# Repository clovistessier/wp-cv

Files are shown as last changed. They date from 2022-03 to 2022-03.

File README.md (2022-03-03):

# Waaave_Pool Eurorack CV Interface Module
The Waaave_Pool Eurorack CV Interface Module is a Eurorack module that allows you to use control voltage from a Eurorack modular synthesizer to modulate any of the 16 continuous parameters of the Waaave_Pool video synthesis system. Use CV from LFOs, sequencers, envelopes, S+H, and more to animate your video feedback. Used in conjuction with a conventional Eurorack synth patch, you can achieve nuanced syncing between your audio and video for a cohesive audiovisual performance. Due to the framebuffer based implementation of Waaave_Pool, the best visual results are using CV that changes at a speed lower than the framerate of the system.

## Revision B.
This version of the module connects directly to the GPIO pins of the Raspberry Pi 3B+ running Waaave_Pool. A limited run of these modules was produced and sold in August 2020. This version is intended to be used with LZX compatible eurorack modules and complies with the [LZX Patchable Video Standard](https://community.lzxindustries.net/t/the-lzx-patchable-video-standard/842) for "Animation Speed" CV (<30Hz), whereas +/-1V corresponds to +/-100% of the parameters range.
### Features
- 16 CV inputs expecting +/-1V (+/-12V tolerant)
- Bipolar attenuator aka attenuverter (-n to n) on each input
- Positive and Negative clipping for voltages outside the expected range
### Usage
All of the files required to build your own are included. You can upload the zipped gerber files to your PCB manufacturer of choice (JLCPCB has been used successfully in the past). Ordering an SMT stencil with the board is highly recommended due to the large quantity of SMD components. 

The KiCAD project files are also included, open the .pro file with KiCAD to view the project.

[Mouser Project Link](https://www.mouser.com/ProjectManager/ProjectDetail.aspx?AccessID=e002599eb7) for easy parts ordering. Don't forget the knobs and jacks from [Thonk](thonk.co.uk)!

The included front panel gerber files can be used to order an FR-4 front panel at the same time as the PCBs. You may get a follow up email from the PCB manufacturer since they assume that a PCB with no copper traces is probably unintentional.

To use the module with Waaave_Pool, you will need a 40-Pin IDC ribbon cable to connect betweent the header at the bottom of the module and the GPIO header of the Raspberry Pi. You will also need to be running a CV-compatible firmware version, which can be found all the way at the bottom of the [VSERPI Hardware and Images page](https://andreijaycreativecoding.com/VSERPI-hardware-and-images).

## Revision C. (WIP)
This version of the module incorporates an ESP32 microcontroller to handle the analog to digital conversion, and trasmits the information using [OSC](https://ccrma.stanford.edu/groups/osc/index.html) to Waaave_Pool over Ethernet and/or Wi-Fi. This version is intended to work with +/-5V control voltage, allowing for a much wider range of compatible CV sources from the Eurorack world, beyond just LZX. Due to the inherent flexibility of OSC, this module could also be used to send CV information to something other than Waaave_Pool, such as an application running on your computer. Development is still ongoing.

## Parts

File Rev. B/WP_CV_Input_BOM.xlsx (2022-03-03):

Reference | Quantity | Value | Footprint | Vendor | Mouser P/N | Price | Ext. Price | Website | Description
C1 C2 | 2 | 10u 25V | Capacitor_THT:CP_Radial_D5.0mm_P2.00mm | Mouser | 667-ECE-A1VKS100 | $0.28 | $0.56 | https://www.mouser.com/ProductDetail/667-ECE-A1VKS100 | Aluminum Electrolytic Capacitors - Radial Leaded 10UF 35V KS RADIAL
C11 C12 | 2 | 10u | Capacitor_Tantalum_SMD:CP_EIA-2012-15_AVX-P | Mouser | 74-TMCP0J106MTRF | $0.36 | $0.72 | https://www.mouser.com/ProductDetail/74-TMCP0J106MTRF | Tantalum Capacitors - Solid SMD 7volts 10uF 20% Molded Case, 0805
C13 C14 C15 C16 C17 C18 C19 C20 C21 C22 C23 C24 C25 C26 C27 C28 C29 C3 C30 C31 C32 C33 C34 C35 C36 C37 C38 C39 C4 C40 C41 C42 C43 C44 C5 C6 C8 C9 | 38 | 100n | Capacitor_SMD:C_0603_1608Metric | Mouser | 80-C0603C104Z3V | $0.03 | $1.22 | https://www.mouser.com/ProductDetail/80-C0603C104Z3V | Multilayer Ceramic Capacitors MLCC - SMD/SMT 25V 0.1uF 0603 Y5V -20/+80%
C10 C7 | 2 | 1u | Capacitor_SMD:C_0603_1608Metric | Mouser | 80-C0603C105K9P | $0.10 | $0.20 | https://www.mouser.com/ProductDetail/80-C0603C105K9P | Multilayer Ceramic Capacitors MLCC - SMD/SMT 1uF 16.0V
D1 D2 | 2 | SM4001 | Diode_SMD:D_SOD-123 | Mouser | 833-SM4001PL-TP | $0.20 | $0.40 | https://www.mouser.com/ProductDetail/833-SM4001PL-TP | Rectifiers Standard 50V 1A
D3 | 1 | LM4040DBZ-2.0 | Package_TO_SOT_SMD:SOT-23 | Mouser | 700-LM4040AEM3-2.1T | $2.36 | $2.36 | https://www.mouser.com/ProductDetail/700-LM4040AEM3-2.1T | Voltage References Improved Precision Micropower Shunt Voltage Reference with Multiple Reverse Breakdown Voltages
D10 D11 D12 D13 D14 D15 D16 D17 D18 D19 D20 D21 D22 D23 D24 D25 D26 D27 D28 D29 D30 D31 D32 D33 D34 D35 D4 D5 D6 D7 D8 D9 | 32 | 1N4148W | Diode_SMD:D_SOD-123 | Mouser | 621-1N4148W-F | $0.16 | $5.12 | https://www.mouser.com/ProductDetail/621-1N4148W-F | Diodes - General Purpose, Power, Switching SURFACE MOUNT FAST SWITCHING DIODE
FB1 FB2 | 2 | Ferrite_Bead | Inductor_SMD:L_0603_1608Metric | Mouser | 875-MI0603J680R-10 | $0.10 | $0.20 | https://www.mouser.com/ProductDetail/875-MI0603J680R-10 | Ferrite Beads 68ohms 100MHz 1A Monolithic 0603 SMD
J1 | 1 | Eurorack_Power_Header_02x08 | Connector_PinHeader_2.54mm:PinHeader_2x08_P2.54mm_Vertical | Mouser | 649-1012938191601BLF | $0.48 | $0.48 | https://www.mouser.com/ProductDetail/649-1012938191601BLF | Headers & Wire Housings ECONOSTIK HEADER DR VT TH 2X8
J2 | 1 | Raspberry_Pi_2_3_GPIO_Header | Connector_PinHeader_2.54mm:PinHeader_2x20_P2.54mm_Vertical | Mouser | 649-1012938194002BLF | $1.11 | $1.11 | https://www.mouser.com/ProductDetail/649-1012938194002BLF | Headers & Wire Housings ECONOSTIK HEADER DR VT TH 2X20
R1 R109 R110 R112 R113 R115 R116 R118 R119 R120 R121 R122 R123 R13 R14 R16 R17 R19 R2 R20 R22 R23 R24 R25 R26 R27 R45 R46 R48 R49 R51 R52 R54 R55 R56 R57 R58 R59 R77 R78 R80 R81 R83 R84 R86 R87 R88 R89 R90 R91 | 50 | 10K | Resistor_SMD:R_0603_1608Metric | Mouser | 667-ERJ-3EKF1002V | $0.05 | $2.50 | https://www.mouser.com/ProductDetail/667-ERJ-3EKF1002V | Thick Film Resistors - SMD 0603 10Kohms 1% AEC-Q200
R124 R125 R126 R127 R128 R129 R130 R131 R28 R29 R30 R31 R32 R33 R34 R35 R60 R61 R62 R63 R64 R65 R66 R67 R92 R93 R94 R95 R96 R97 R98 R99 | 32 | 1K | Resistor_SMD:R_0603_1608Metric | Mouser | 667-ERJ-PA3F1001V | $0.06 | $1.92 | https://www.mouser.com/ProductDetail/667-ERJ-PA3F1001V | Thick Film Resistors - SMD 0603 1Kohm 1% Anti-Surge AEC-Q200
R108 R111 R114 R117 R12 R15 R18 R21 R3 R44 R47 R50 R53 R76 R79 R82 R85 | 17 | 4.99K | Resistor_SMD:R_0603_1608Metric | Mouser | 603-RC0603FR-104K99L | $0.02 | $0.34 | https://www.mouser.com/ProductDetail/603-RC0603FR-104K99L | Thick Film Resistors - SMD 4.99K ohm 1% 75V General Purpose
R100 R101 R102 R103 R36 R37 R38 R39 R4 R5 R6 R68 R69 R7 R70 R71 | 16 | 100K | Resistor_SMD:R_0603_1608Metric | Mouser | 603-RC0603FR-07100KL | $0.02 | $0.32 | https://www.mouser.com/ProductDetail/603-RC0603FR-07100KL | Thick Film Resistors - SMD 100K OHM 1%
R10 R104 R105 R106 R107 R11 R40 R41 R42 R43 R72 R73 R74 R75 R8 R9 | 16 | 499R | Resistor_SMD:R_0603_1608Metric | Mouser | 71-CRCW0603-499-E3 | $0.03 | $0.48 | https://www.mouser.com/ProductDetail/71-CRCW0603-499-E3 | Thick Film Resistors - SMD 1/10watt 499ohms 1%
U1 U2 | 2 | MCP3008 | Package_SO:SOIC-16_3.9x9.9mm_P1.27mm | Mouser | 579-MCP3008T-I/SL | $2.19 | $4.38 | https://www.mouser.com/ProductDetail/579-MCP3008T-I-SL | Analog to Digital Converters - ADC 10-bit SPI 8 Chl IND TEMP, SOIC16
U3 | 1 | TL072 | Package_SO:SOIC-8_3.9x4.9mm_P1.27mm | Mouser | 595-TL072CDR | $0.41 | $0.41 | https://www.mouser.com/ProductDetail/595-TL072CDR | Operational Amplifiers - Op Amps Dual JFET Op Amp
U10 U11 U12 U13 U14 U15 U16 U17 U18 U19 U4 U5 U6 U7 U8 U9 | 16 | TL074 | Package_SO:SOIC-14_3.9x8.7mm_P1.27mm | Mouser | 511-TL074IDT | $0.48 | $7.68 | https://www.mouser.com/ProductDetail/511-TL074IDT | Operational Amplifiers - Op Amps Quad Low Noise JFET
J10 J11 J12 J13 J14 J15 J16 J17 J18 J3 J4 J5 J6 J7 J8 J9 | 16 | Thonkiconn_Mono | Connector_Audio_Extra:Jack_3.5mm_QingPu_WQP-PJ398SM_Vertical_CircularHoles_Numbered_Pads | Thonk |  | $0.43 | $6.88 | https://www.thonk.co.uk/shop/thonkiconn/ | Thonkiconn Mono 3.5mm Audio Jack
RV1 RV10 RV11 RV12 RV13 RV14 RV15 RV16 RV2 RV3 RV4 RV5 RV6 RV7 RV8 RV9 | 16 | B10K Center Detent | Potentiometer_THT_Extra:Potentiometer_Alpha_RD901F-40-00D_Single_Vertical_CircularHoles | Thonk |  | $1.04 | $16.64 | https://www.thonk.co.uk/shop/ttpots/ | Song Huei 9mm Tall Trimmer Potentiometer
 |  |  |  |  |  | Total Price: | $53.92
 |  |  |  |  |  |  |  | Mouser Project Page:
 |  |  |  |  |  |  |  | https://www.mouser.com/ProjectManager/ProjectDetail.aspx?AccessID=e002599eb7

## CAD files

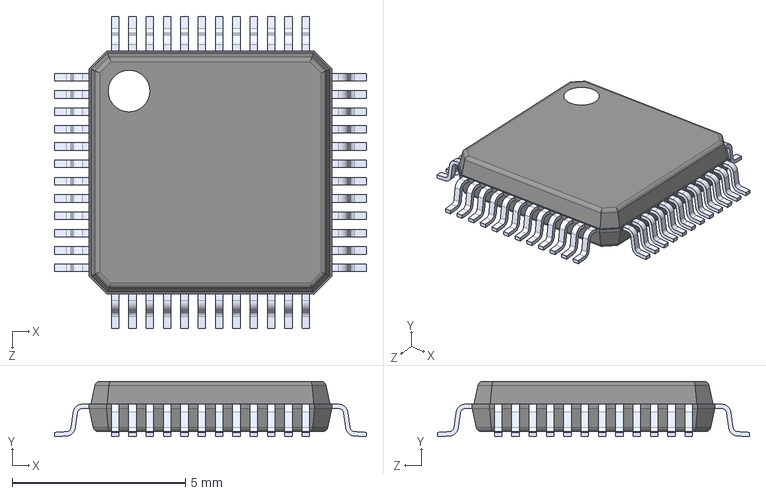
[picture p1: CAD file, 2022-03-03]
Rev. C/Hardware Design Files/KiCAD Project Files/PROJECT_SYMBOLS/W5500/W5500.step
9.00 x 1.60 x 9.00 mm

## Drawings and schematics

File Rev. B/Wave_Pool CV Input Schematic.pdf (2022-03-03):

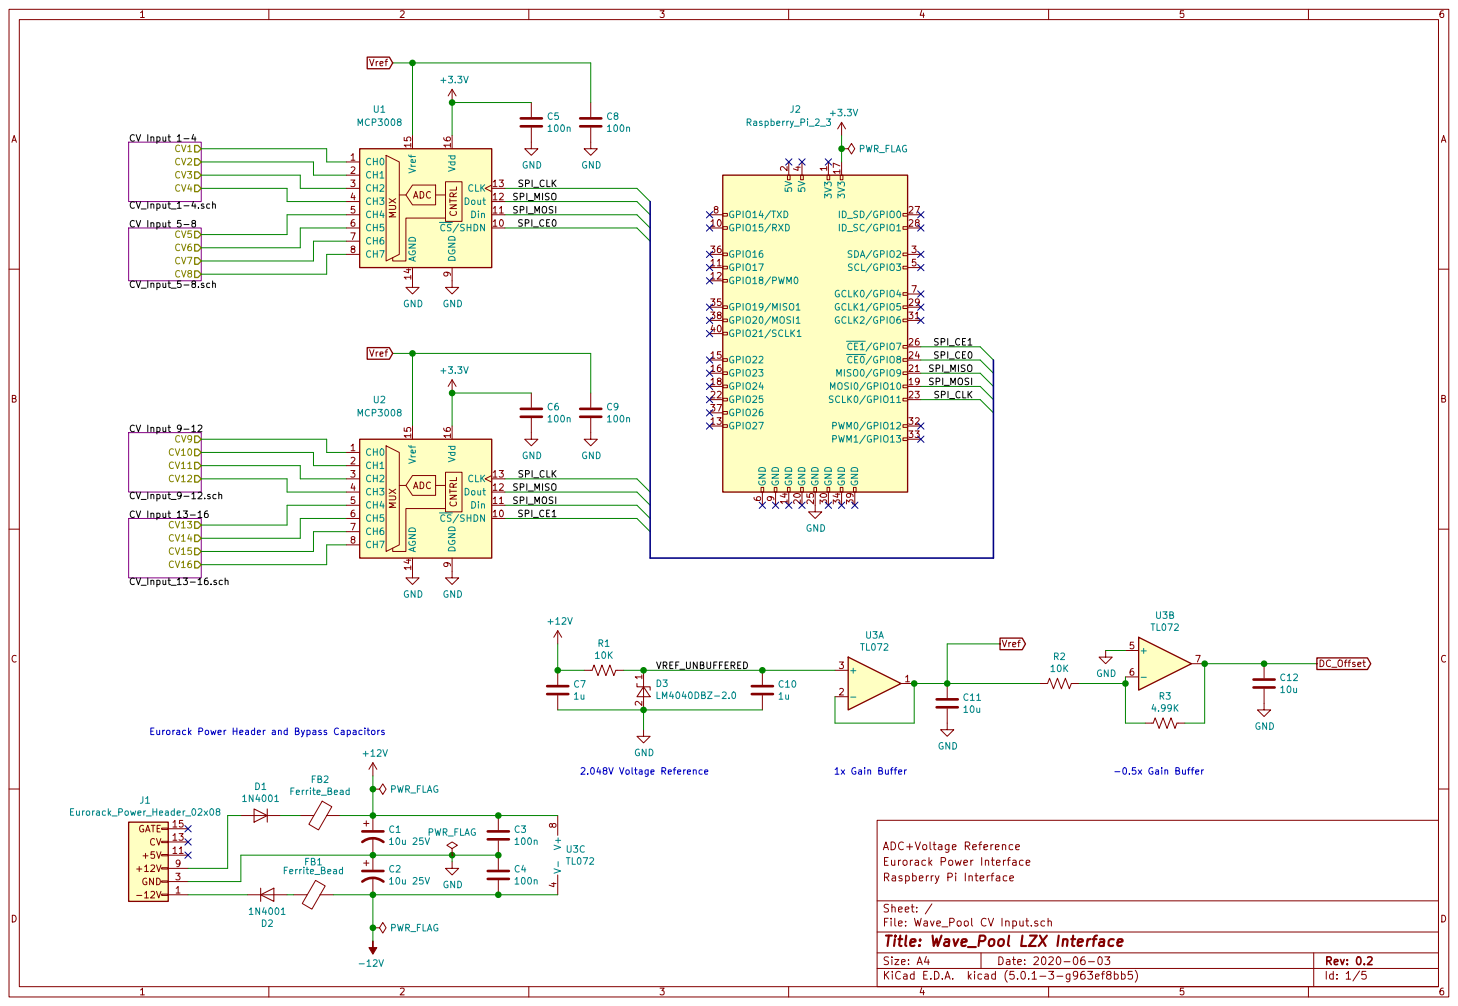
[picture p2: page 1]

9 U1 MCP3008 ADC MUX CNTRL CH0 1 CS/SHDN 10 Din 11 Dout 12 CLK 13 AGND 14 Vref 15 Vdd 16 CH1 2 CH2 3 CH3 4 CH4 5 CH5 6 CH6 7 CH7 8 DGND

File: Wave_Pool CV Input.sch Sheet: / Raspberry Pi Interface Eurorack Power Interface ADC+Voltage Reference

Id: 1/5 Title: Wave_Pool LZX Interface

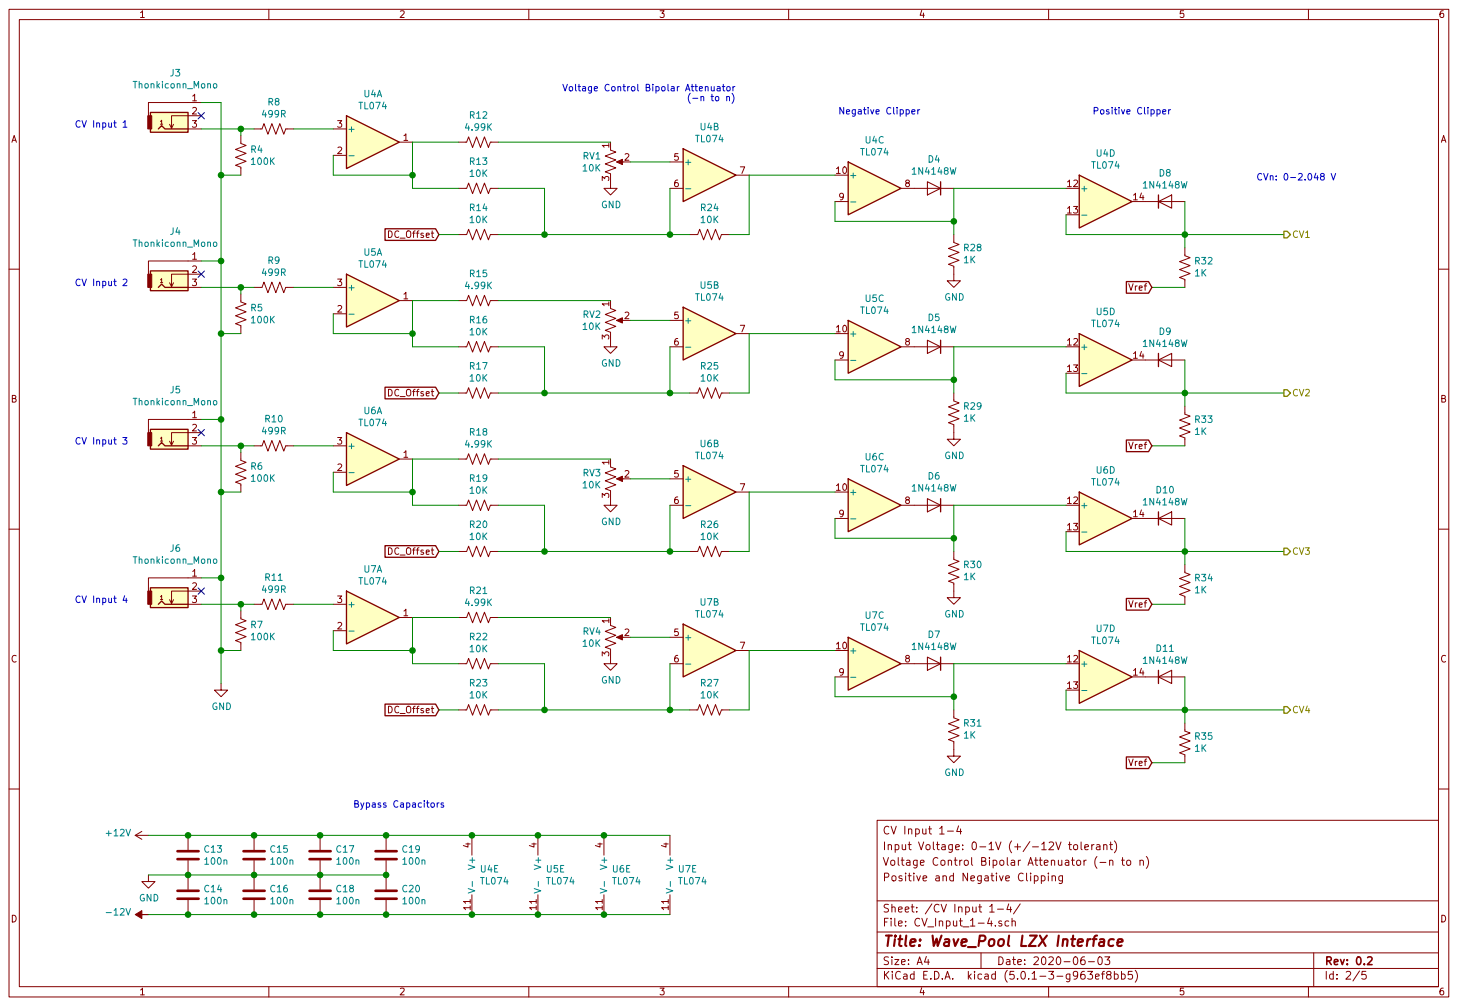
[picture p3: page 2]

Voltage Control Bipolar Attenuator

Input Voltage: 0-1V (+/-12V tolerant)
Voltage Control Bipolar Attenuator (-n to n)
Positive and Negative Clipping

Sheet: /CV Input 1-4/
File: CV_Input_1-4.sch
Id: 2/5 Title: Wave_Pool LZX Interface

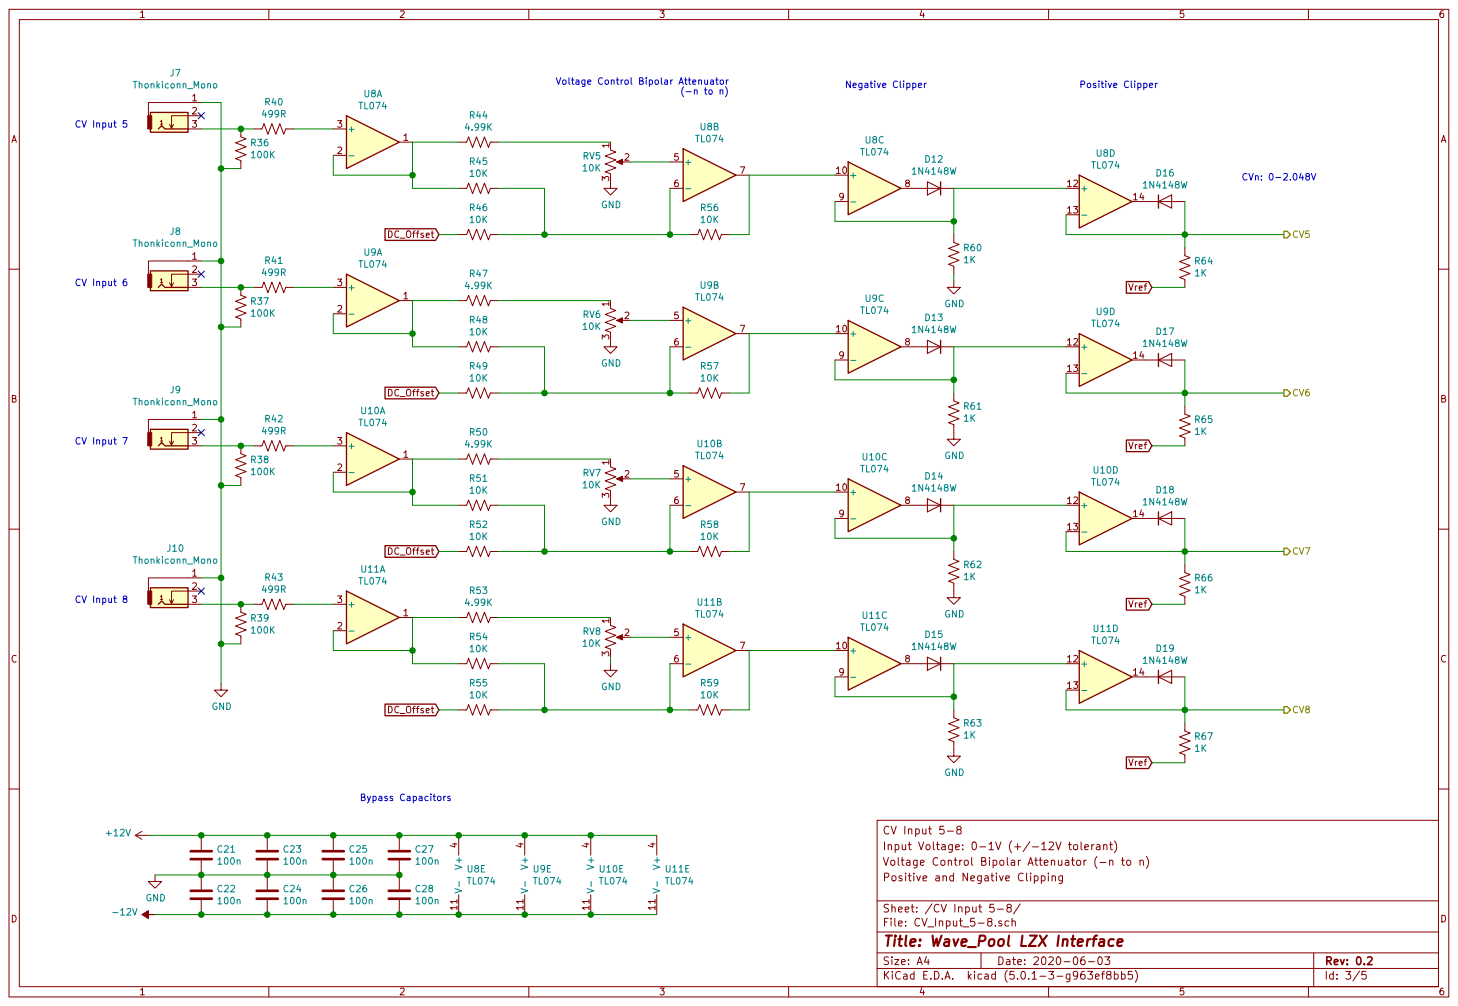
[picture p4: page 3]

Voltage Control Bipolar Attenuator

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

Sheet: /CV Input 5-8/
File: CV_Input_5-8.sch
Id: 3/5 Title: Wave_Pool LZX Interface

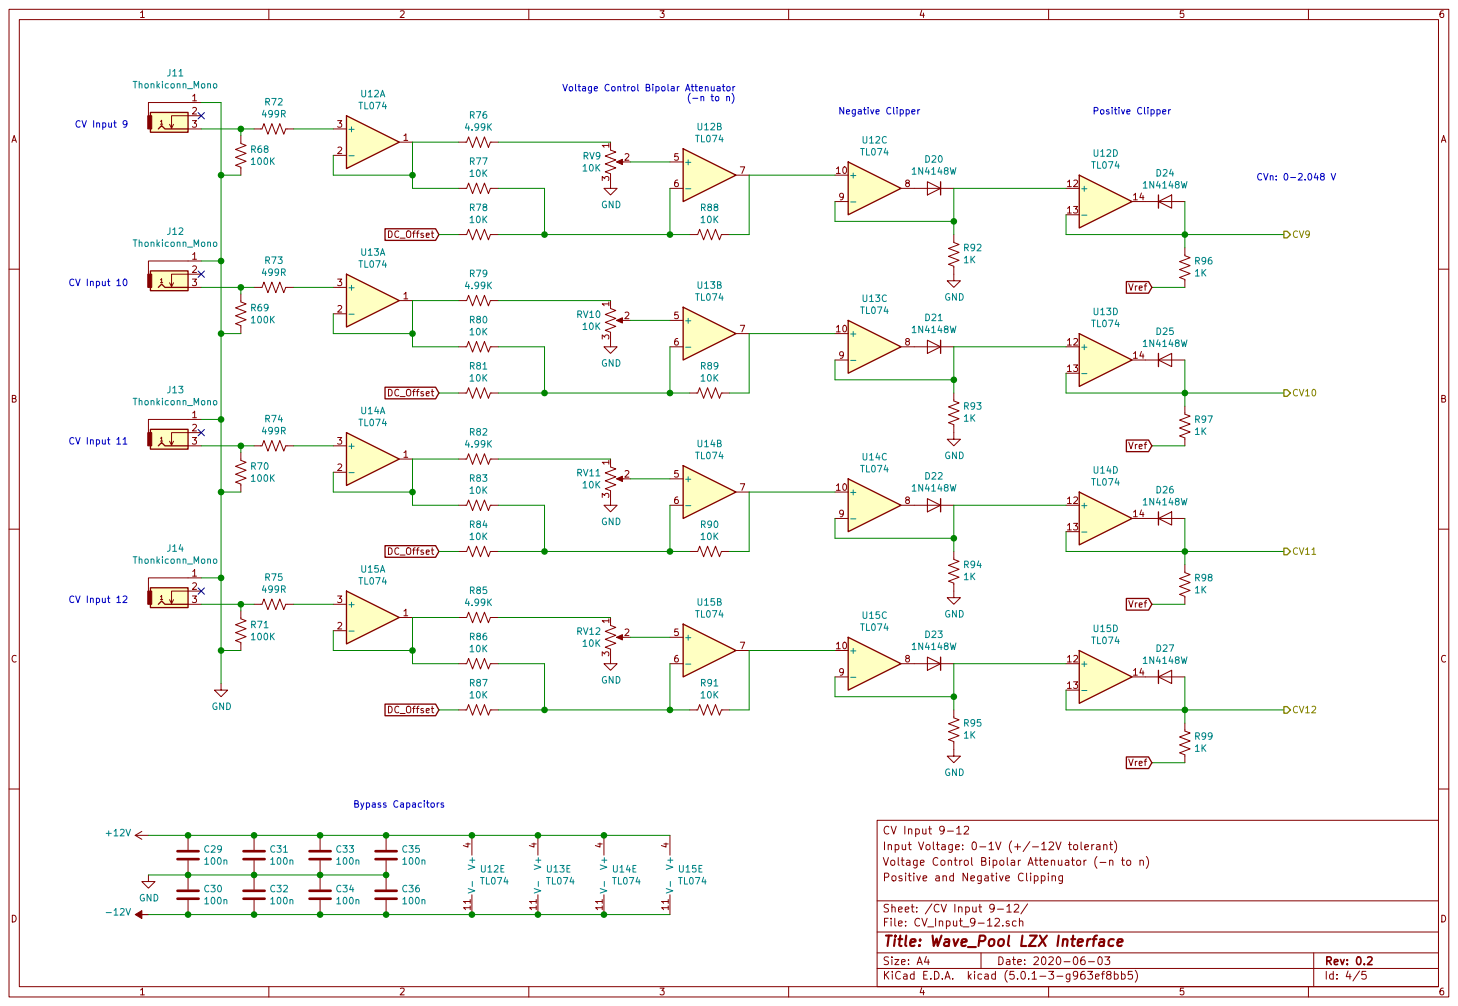
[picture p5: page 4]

Voltage Control Bipolar Attenuator

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

Sheet: /CV Input 9-12/
File: CV_Input_9-12.sch
Id: 4/5 Title: Wave_Pool LZX Interface

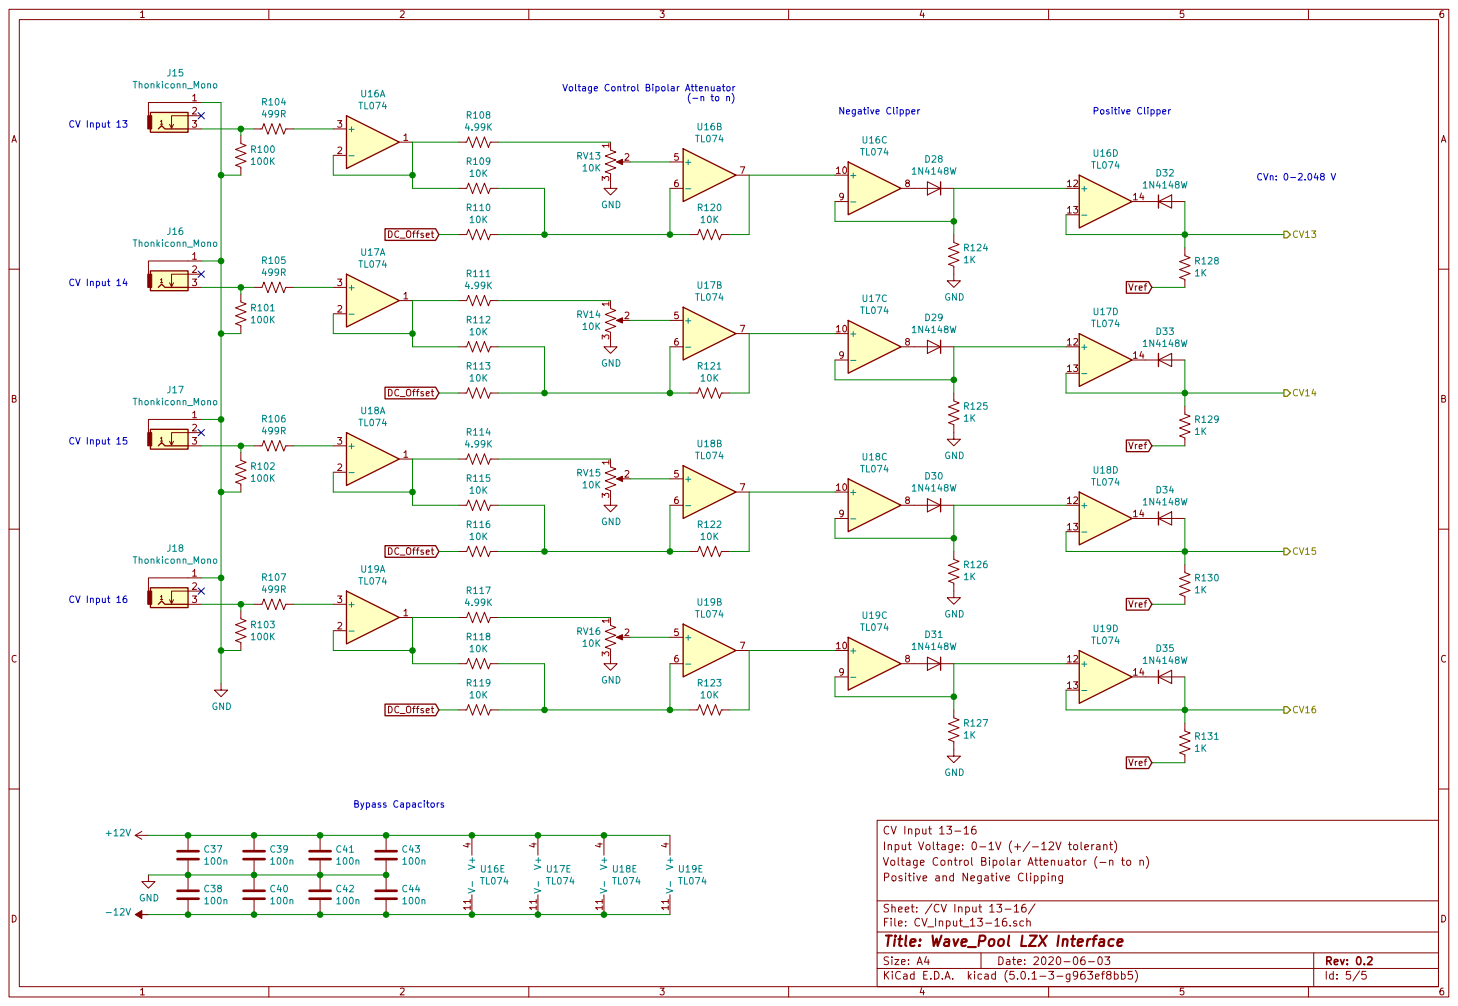
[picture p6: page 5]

Voltage Control Bipolar Attenuator

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

Sheet: /CV Input 13-16/
File: CV_Input_13-16.sch
Id: 5/5 Title: Wave_Pool LZX Interface

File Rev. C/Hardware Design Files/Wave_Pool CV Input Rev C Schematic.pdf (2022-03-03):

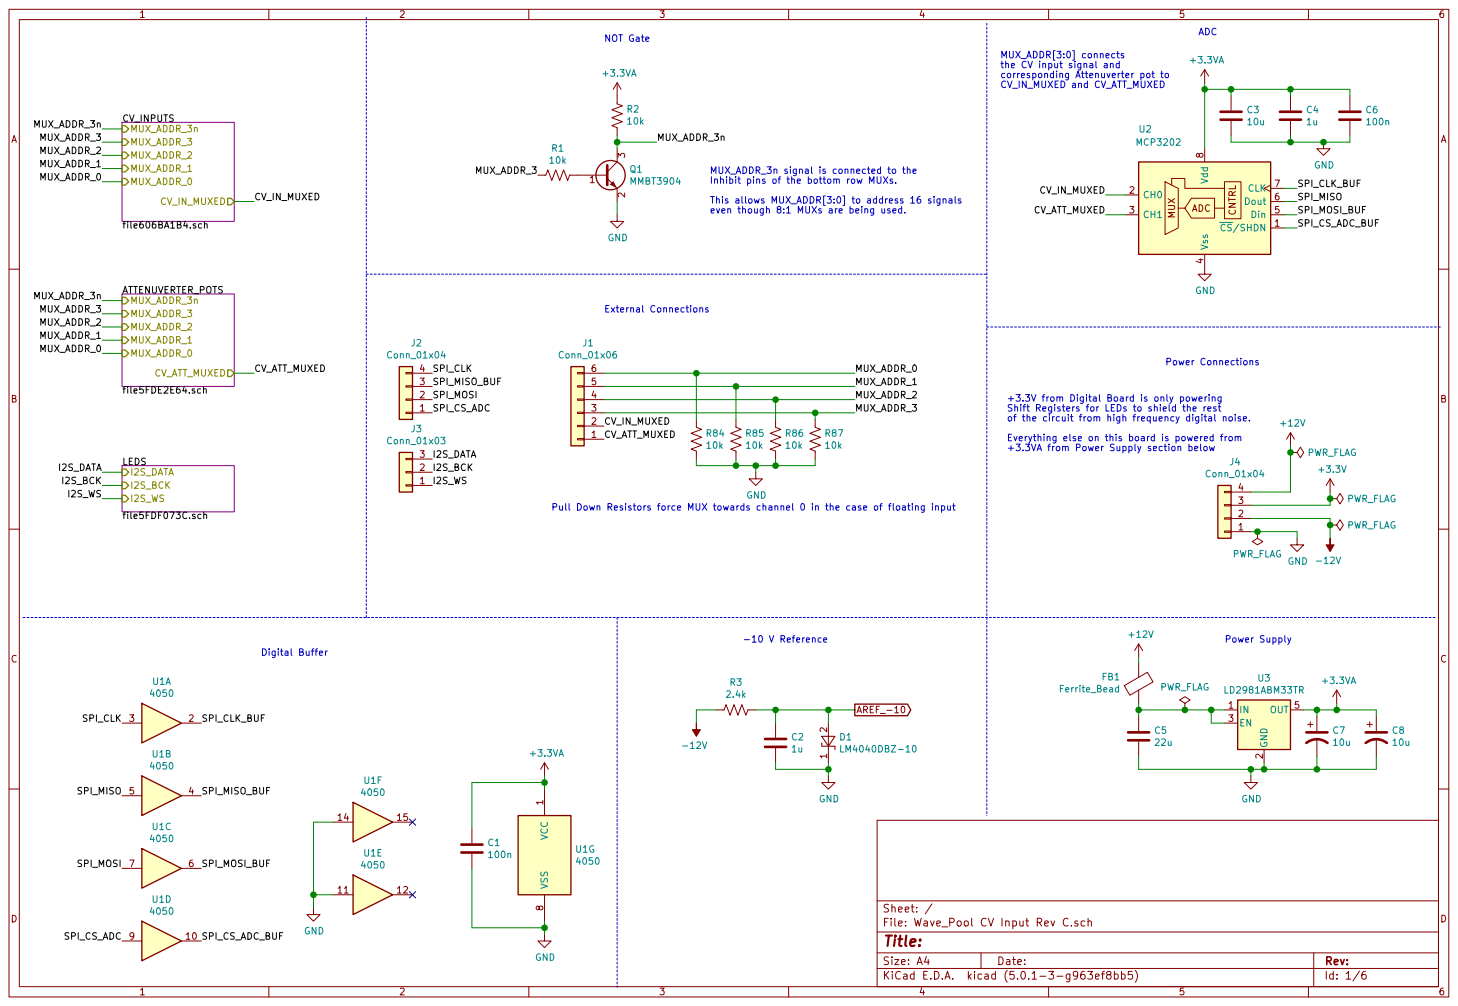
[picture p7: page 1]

MUX_ADDR[3:0] connects
the CV input signal and
corresponding Attenuverter pot to CV_IN_MUXED and CV_ATT_MUXED

MUX_ADDR_3n signal is connected to the
Inhibit pins of the bottom row MUXs.
This allows MUX_ADDR[3:0] to address 16 signals
even though 8:1 MUXs are being used.

+3.3V from Digital Board is only powering
Shift Registers for LEDs to shield the rest
of the circuit from high frequency digital noise.
Everything else on this board is powered from
+3.3VA from Power Supply section below

Pull Down Resistors force MUX towards channel 0 in the case of floating input

File: Wave_Pool CV Input Rev C.sch Sheet: /
Id: 1/6 Title:

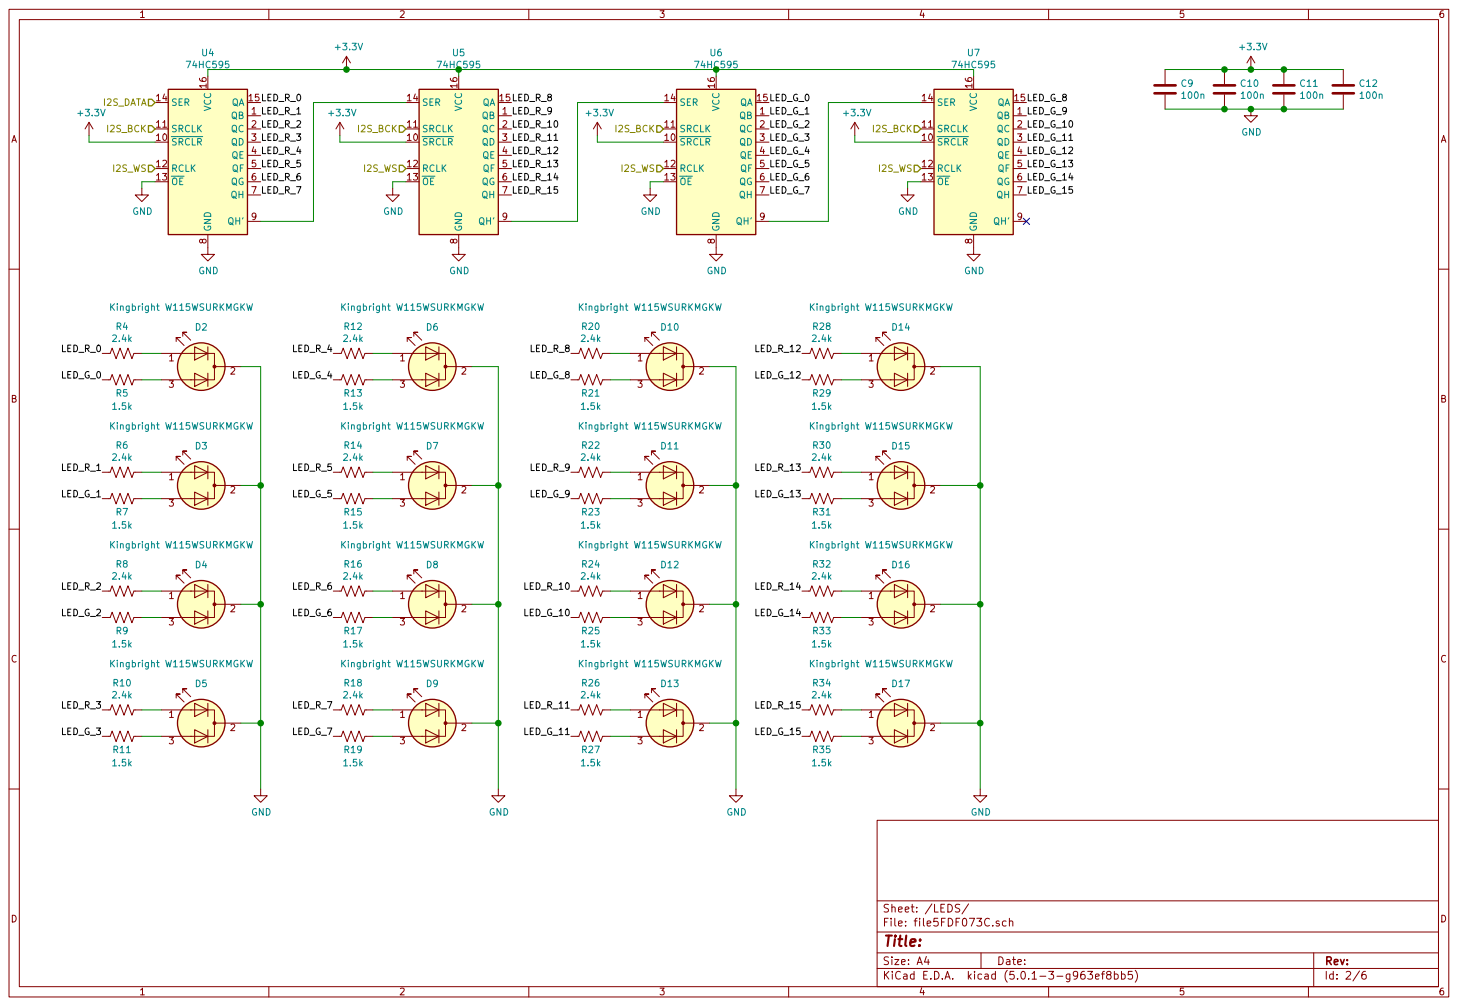
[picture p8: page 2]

Id: 2/6 Title: File: file5FDF073C.sch Sheet: /LEDS/

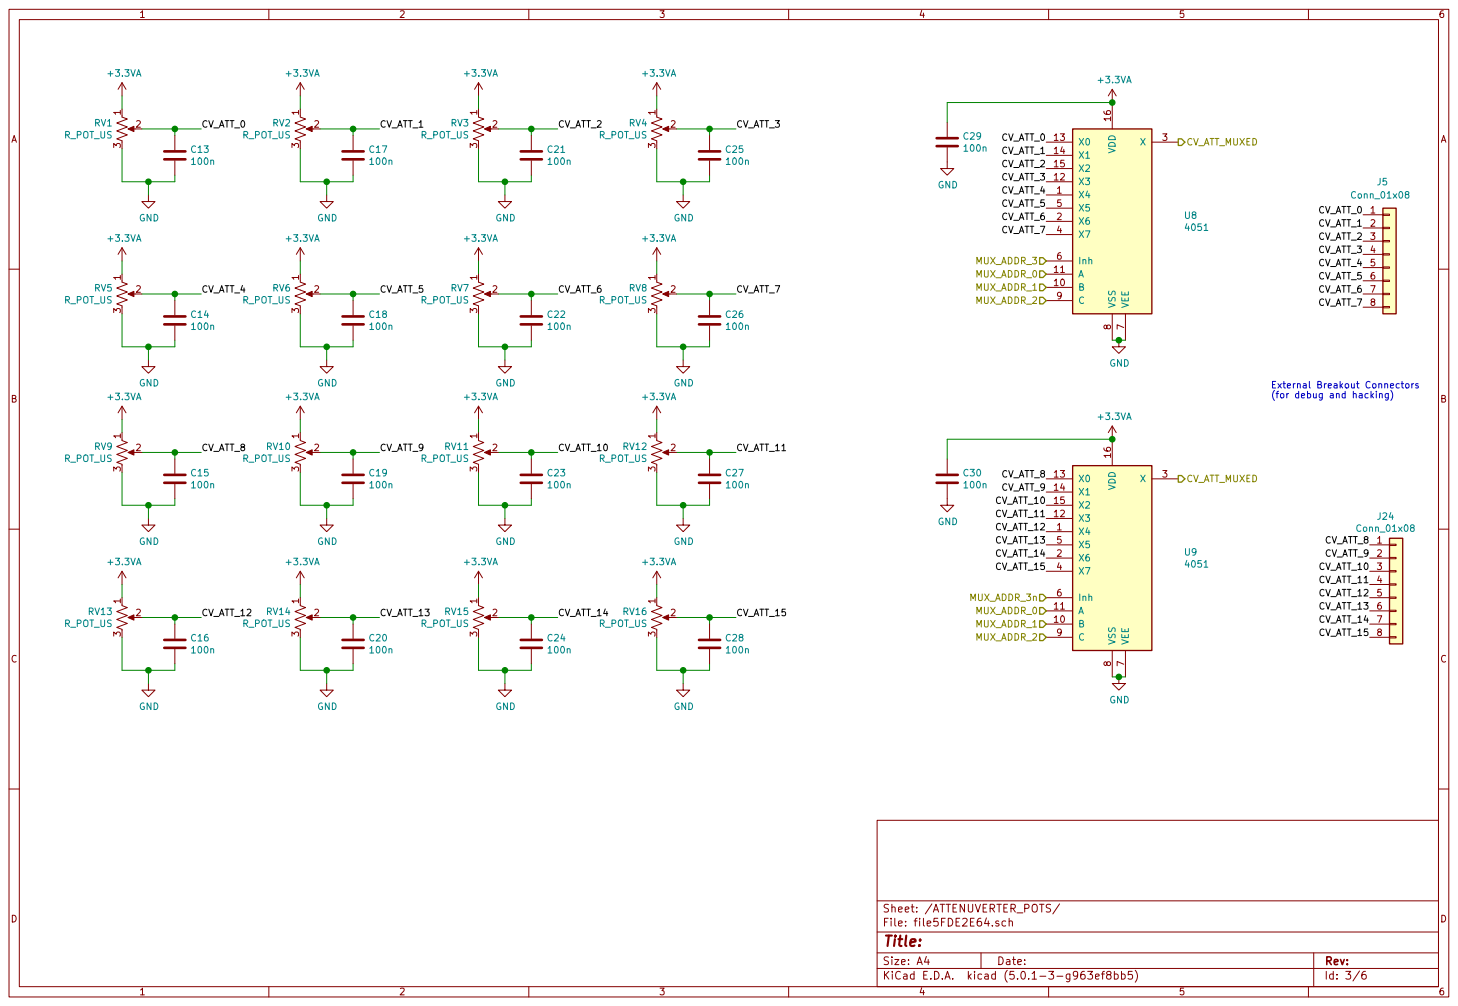
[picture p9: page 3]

J24 Conn_01x08 External Breakout Connectors
(for debug and hacking)

Id: 3/6 Title: File: file5FDE2E64.sch Sheet: /ATTENUVERTER_POTS/

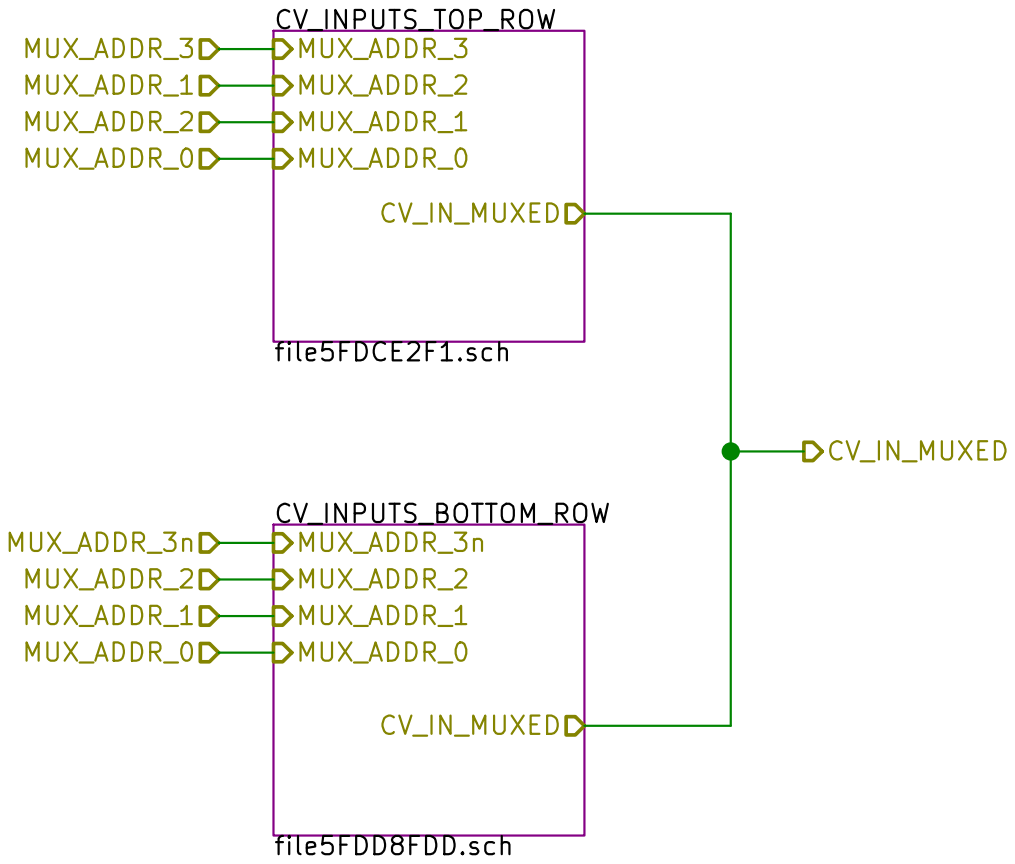
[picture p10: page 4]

Id: 4/6 Title: File: file606BA1B4.sch Sheet: /CV_INPUTS/

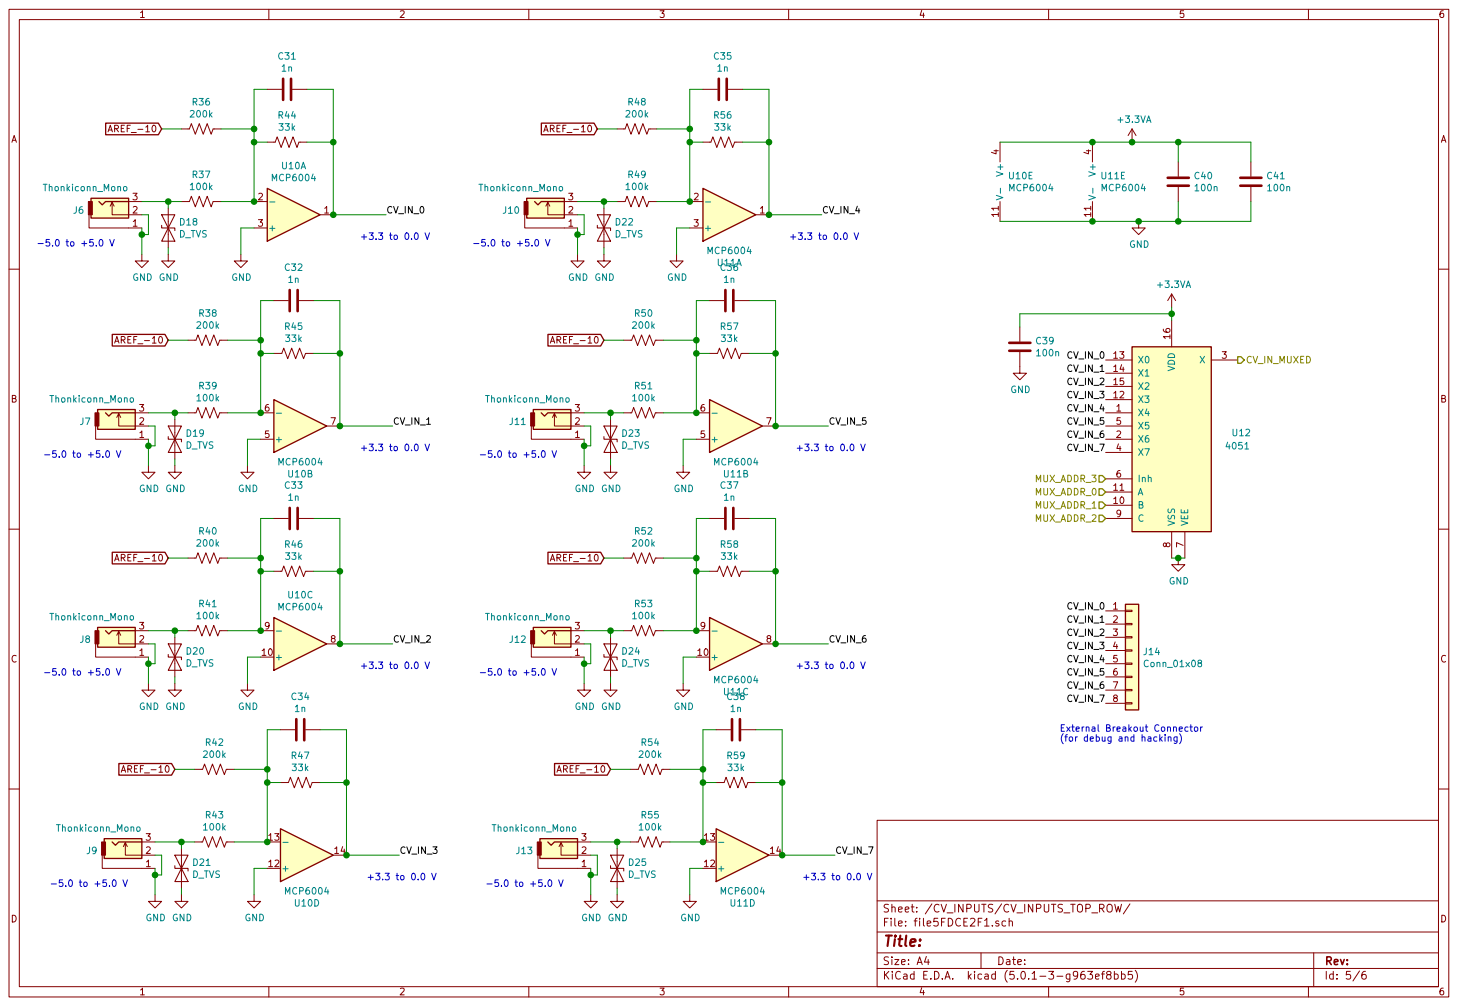
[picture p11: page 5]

External Breakout Connector (for debug and hacking)

Id: 5/6 Title: File: file5FDCE2F1.sch Sheet: /CV_INPUTS/CV_INPUTS_TOP_ROW/

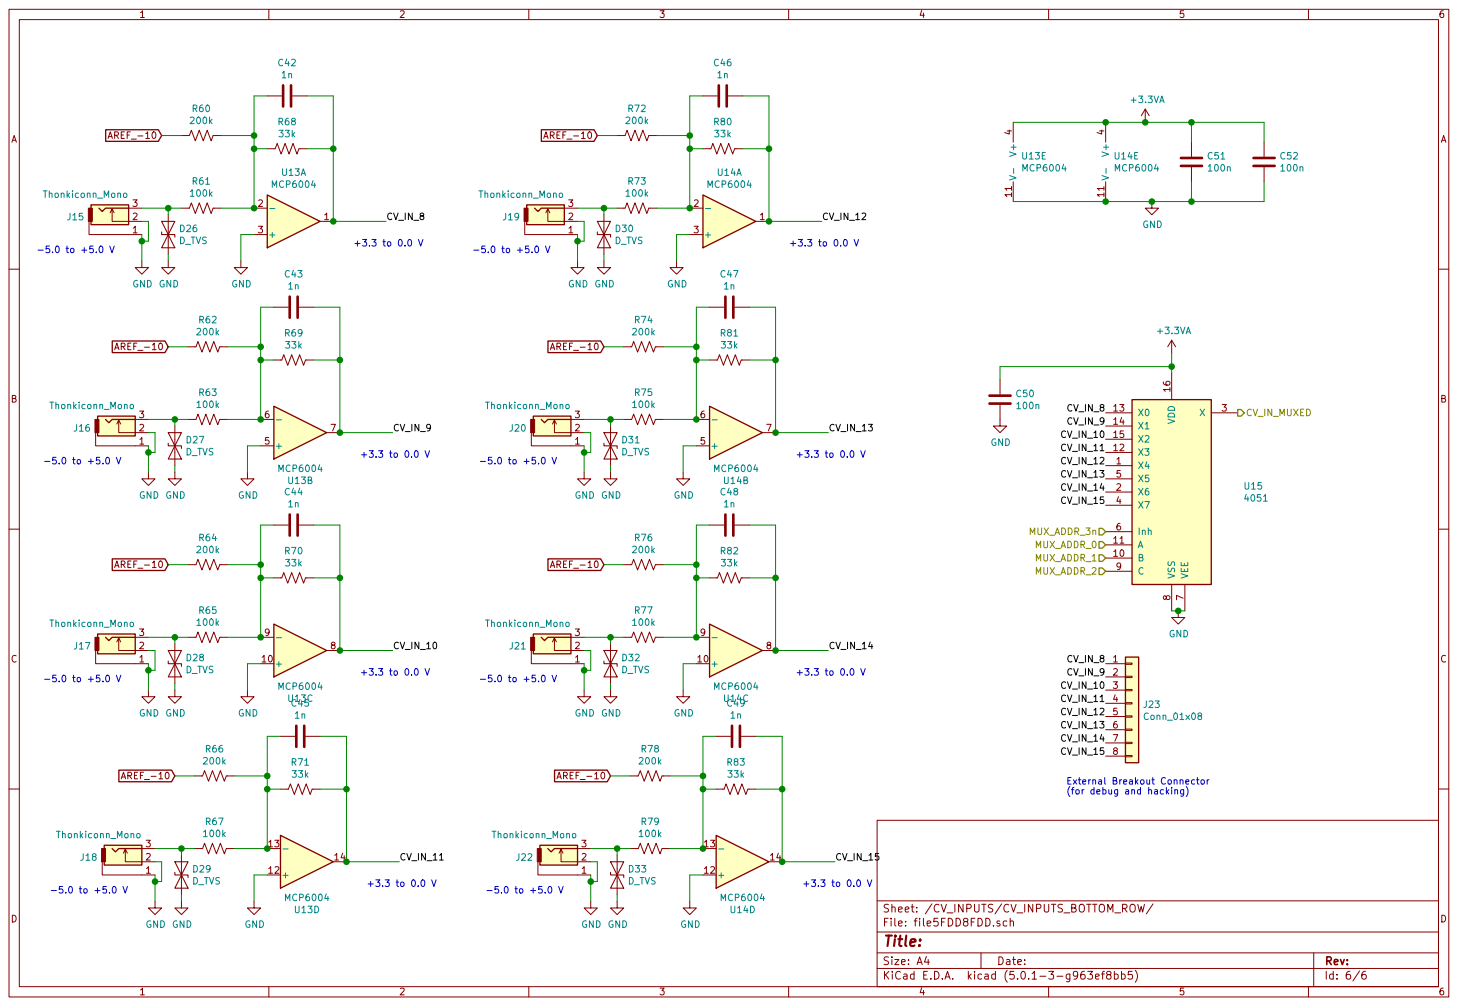
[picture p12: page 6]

External Breakout Connector (for debug and hacking)

Id: 6/6 Title: File: file5FDD8FDD.sch Sheet: /CV_INPUTS/CV_INPUTS_BOTTOM_ROW/

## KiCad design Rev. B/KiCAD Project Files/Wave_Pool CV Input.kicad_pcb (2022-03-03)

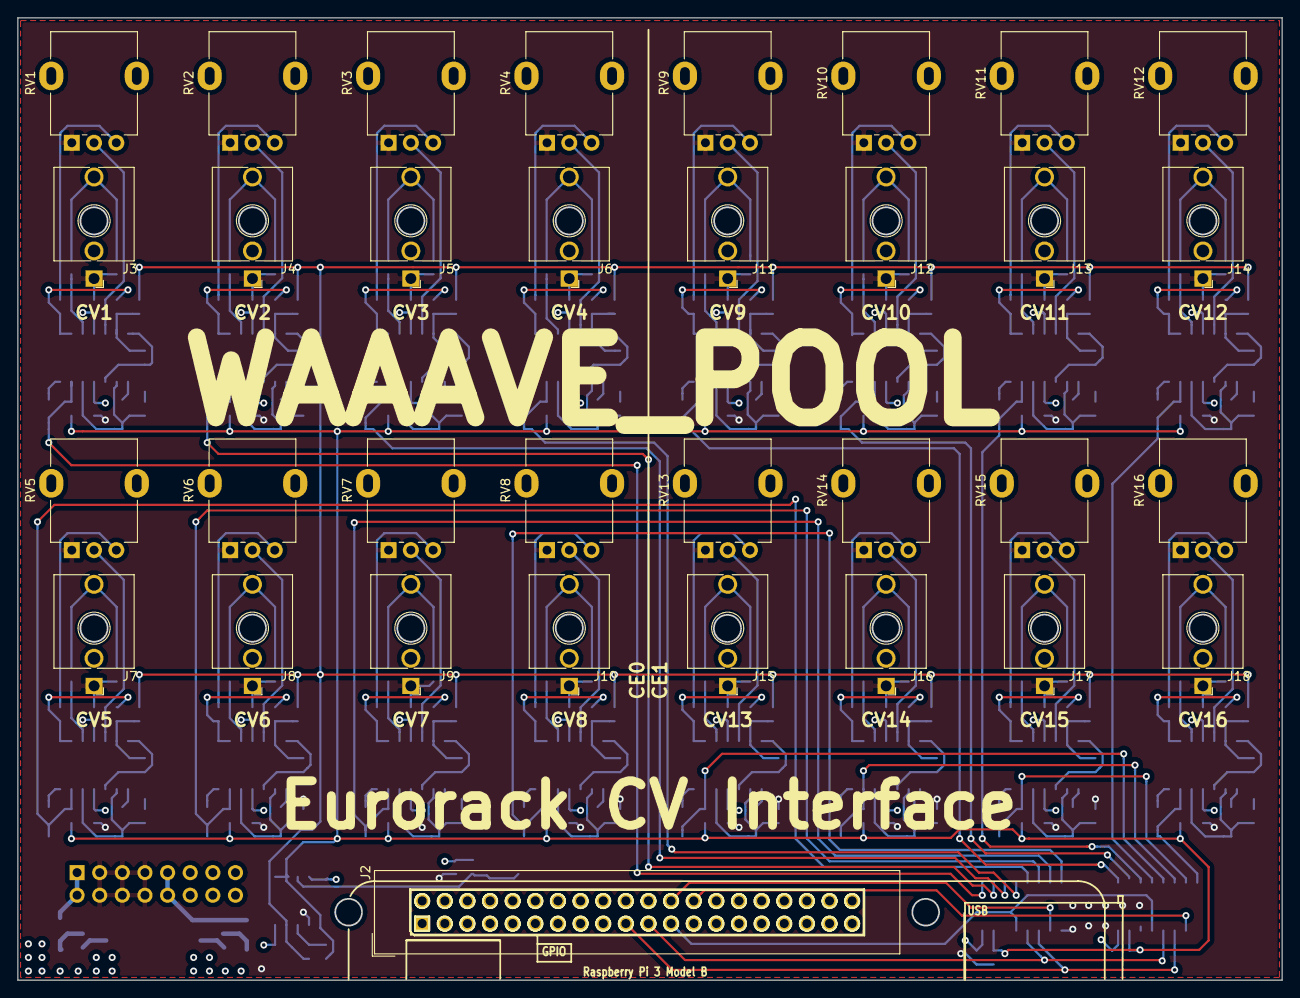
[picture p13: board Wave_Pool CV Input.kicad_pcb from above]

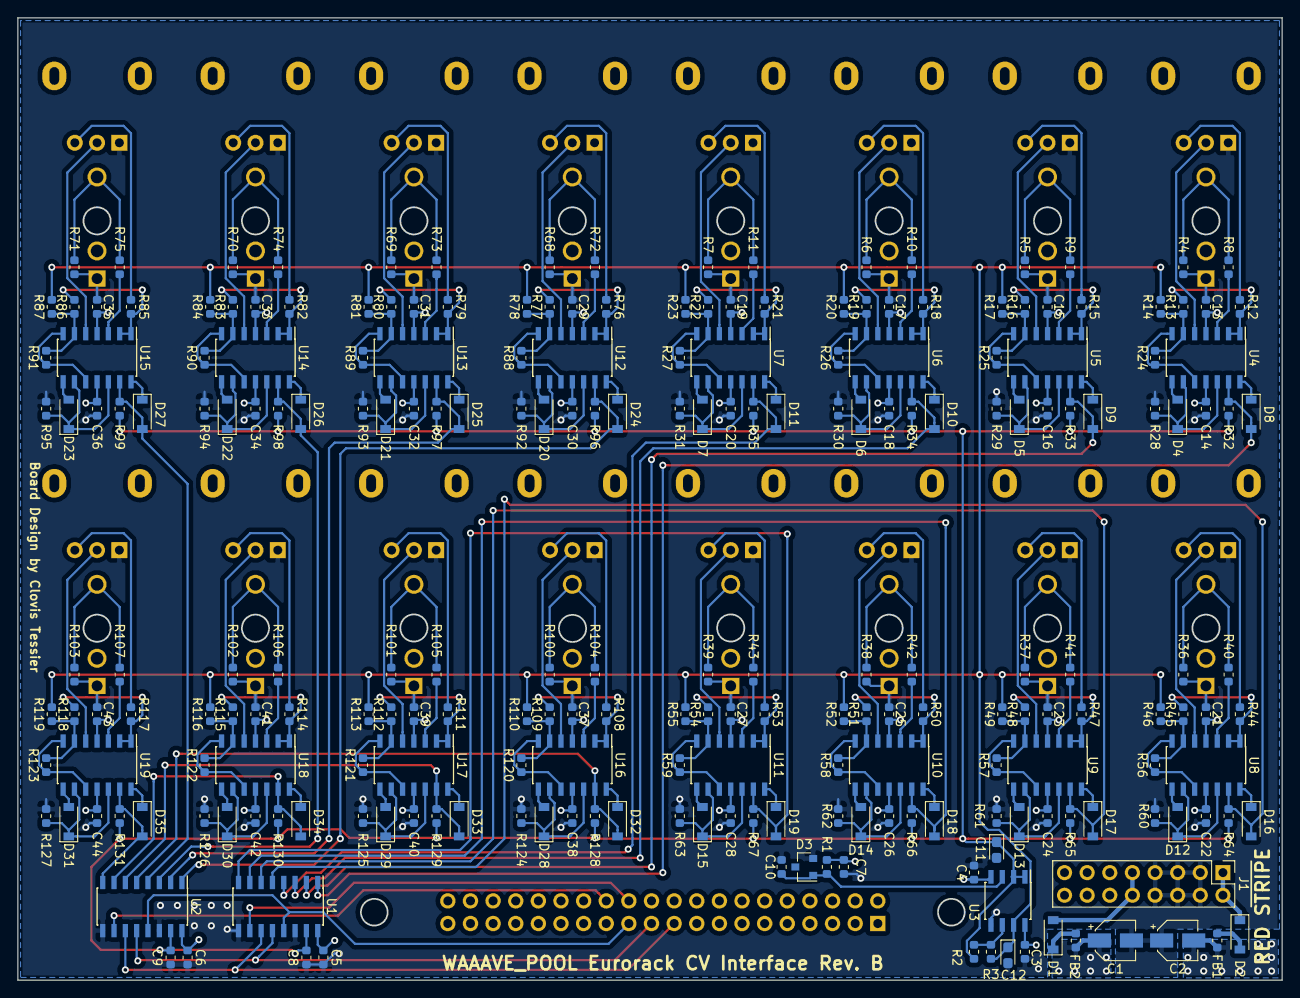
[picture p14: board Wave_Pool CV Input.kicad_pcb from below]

Board: 4 copper layers, 141.9 x 108.0 mm, 265 parts (232 on the bottom side), 193 nets.

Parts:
C1, C2: 10u 25V; CP_Elec_4x5.4
C3, C4, C5, C6, C8, C9, C13, C14, C15, C16, C17, C18, C19, C20, C21, C22, C23, C24, C25, C26, C27, C28, C29, C30, C31, C32, C33, C34, C35, C36, C37, C38, C39, C40, C41, C42, C43, C44: 100n; C_0603_1608Metric
C7, C10: 1u; C_0603_1608Metric
C11, C12: 10u; CP_EIA-2012-15_AVX-P
D1, D2: SM4001; D_SOD-123
D3: LM4040DBZ-2.0; SOT-23
D4, D5, D6, D7, D8, D9, D10, D11, D12, D13, D14, D15, D16, D17, D18, D19, D20, D21, D22, D23, D24, D25, D26, D27, D28, D29, D30, D31, D32, D33, D34, D35: 1N4148W; D_SOD-123
FB1, FB2: Ferrite_Bead; L_0603_1608Metric
J1: Eurorack_Power_Header_02x08_Hidden_Pins; PinHeader_2x08_P2.54mm_Vertical
J2: Raspberry_Pi_2_3; IDC-Header_2x20_P2.54mm_Vertical
J3, J4, J5, J6, J7, J8, J9, J10, J11, J12, J13, J14, J15, J16, J17, J18: Thonkiconn_Mono; Jack_3.5mm_QingPu_WQP-PJ398SM_Vertical_CircularHoles_Number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
R1, R2, R13, R14, R16, R17, R19, R20, R22, R23, R24, R25, R26, R27, R45, R46, R48, R49, R51, R52, R54, R55, R56, R57, R58, R59, R77, R78, R80, R81, R83, R84, R86, R87, R88, R89, R90, R91, R109, R110, R112, R113, R115, R116, R118, R119, R120, R121, R122, R123: 10K; R_0603_1608Metric
R3, R12, R15, R18, R21, R28, R29, R30, R31, R32, R33, R34, R35, R44, R47, R50, R53, R60, R61, R62, R63, R64, R65, R66, R67, R76, R79, R82, R85, R92, R93, R94, R95, R96, R97, R98, R99, R108, R111, R114, R117, R124, R125, R126, R127, R128, R129, R130, R131: 4.99K; R_0603_1608Metric
R4, R5, R6, R7, R36, R37, R38, R39, R68, R69, R70, R71, R100, R101, R102, R103: 100K; R_0603_1608Metric
R8, R9, R10, R11, R40, R41, R42, R43, R72, R73, R74, R75, R104, R105, R106, R107: 499R; R_0603_1608Metric
RV1, RV2, RV3, RV4, RV5, RV6, RV7, RV8, RV9, RV10, RV11, RV12, RV13, RV14, RV15, RV16: 10K; Potentiometer_Alpha_RD901F-40-00D_Single_Vertical
U1, U2: MCP3008; SOIC-16_3.9x9.9mm_P1.27mm
U3: TL072; SOIC-8_3.9x4.9mm_P1.27mm
U4, U5, U6, U7, U8, U9, U10, U11, U12, U13, U14, U15, U16, U17, U18, U19: TL074; SOIC-14_3.9x8.7mm_P1.27mm

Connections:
+3V3: C5.1, C6.1, J2.17, U1.16, U2.16
+12V: C1.1, C3.1, C7.1, C13.1, C15.1, C17.1, C19.1, C21.1, C23.1, C25.1, C27.1, C29.1, C31.1, C33.1, C35.1, C37.1, C39.1, C41.1, C43.1, FB2.1, R1.2, U3.8, U4.4, U5.4, U6.4, U7.4, U8.4, U9.4, U10.4, U11.4, U12.4, U13.4, U14.4, U15.4, U16.4, U17.4, U18.4, U19.4
-12V: C2.2, C4.2, C14.2, C16.2, C18.2, C20.2, C22.2, C24.2, C26.2, C28.2, C30.2, C32.2, C34.2, C36.2, C38.2, C40.2, C42.2, C44.2, FB1.1, U3.4, U4.11, U5.11, U6.11, U7.11, U8.11, U9.11, U10.11, U11.11, U12.11, U13.11, U14.11, U15.11, U16.11, U17.11, U18.11, U19.11
/CV Input 1-4/CV1: D8.2, R32.2, U1.1, U4.13
/CV Input 1-4/CV2: D9.2, R33.2, U1.2, U5.13
/CV Input 1-4/CV3: D10.2, R34.2, U1.3, U6.13
/CV Input 1-4/CV4: D11.2, R35.2, U1.4, U7.13
/CV Input 5-8/CV5: D16.2, R64.2, U1.5, U8.13
/CV Input 5-8/CV6: D17.2, R65.2, U1.6, U9.13
/CV Input 5-8/CV7: D18.2, R66.2, U1.7, U10.13
/CV Input 5-8/CV8: D19.2, R67.2, U1.8, U11.13
/CV Input 9-12/CV9: D24.2, R96.2, U2.1, U12.13
/CV Input 9-12/CV10: D25.2, R97.2, U2.2, U13.13
/CV Input 9-12/CV11: D26.2, R98.2, U2.3, U14.13
/CV Input 9-12/CV12: D27.2, R99.2, U2.4, U15.13
/CV Input 13-16/CV13: D32.2, R128.2, U2.5, U16.13
/CV Input 13-16/CV14: D33.2, R129.2, U2.6, U17.13
/CV Input 13-16/CV15: D34.2, R130.2, U2.7, U18.13
/CV Input 13-16/CV16: D35.2, R131.2, U2.8, U19.13
/SPI_CE0: J2.24, U1.10
/SPI_CE1: J2.26, U2.10
/SPI_CLK: J2.23, U1.13, U2.13
/SPI_MISO: J2.21, U1.12, U2.12
/SPI_MOSI: J2.19, U1.11, U2.11
/VREF_UNBUFFERED: C10.1, D3.1, R1.1, U3.3
DC_Offset: C12.1, R3.1, R14.2, R17.2, R20.2, R23.2, R46.2, R49.2, R52.2, R55.2, R78.2, R81.2, R84.2, R87.2, R110.2, R113.2, R116.2, R119.2, U3.7
GND: C1.2, C2.1, C3.2, C4.1, C5.2, C6.2, C7.2, C8.2, C9.2, C10.2, C11.2, C12.2, C13.2, C14.1, C15.2, C16.1, C17.2, C18.1, C19.2, C20.1, C21.2, C22.1, C23.2, C24.1, C25.2, C26.1, C27.2, C28.1, C29.2, C30.1, C31.2, C32.1, C33.2, C34.1, C35.2, C36.1, C37.2, C38.1, C39.2, C40.1, C41.2, C42.1, C43.2, C44.1, D3.2, J1.3, J1.4, J1.5, J1.6, J1.7, J1.8, J2.25, J3.1, J4.1, J5.1, J6.1, J7.1, J8.1, J9.1, J10.1, J11.1, J12.1, J13.1, J14.1, J15.1, J16.1, J17.1, J18.1, R4.2, R5.2, R6.2, R7.2, R28.1, R29.1, R30.1, R31.1, R36.2, R37.2, R38.2, R39.2, R60.1, R61.1, R62.1, R63.1, R68.2, R69.2, R70.2, R71.2, R92.1, R93.1, R94.1, R95.1, R100.2, R101.2, R102.2, R103.2, R124.1, R125.1, R126.1, R127.1, RV1.1, RV2.1, RV3.1, RV4.1, RV5.1, RV6.1, RV7.1, RV8.1, RV9.1, RV10.1, RV11.1, RV12.1, RV13.1, RV14.1, RV15.1, RV16.1, U1.9, U1.14, U2.9, U2.14, U3.5
unnamed: D1.1, FB2.2
unnamed: D1.2, J1.9, J1.10
unnamed: D2.1, J1.1, J1.2
unnamed: D2.2, FB1.2
unnamed: D4.1, R28.2, U4.9, U4.12
unnamed: D4.2, U4.8
unnamed: D5.1, R29.2, U5.9, U5.12
unnamed: D5.2, U5.8
unnamed: D6.1, R30.2, U6.9, U6.12
unnamed: D6.2, U6.8
unnamed: D7.1, R31.2, U7.9, U7.12
unnamed: D7.2, U7.8
unnamed: D8.1, U4.14
unnamed: D9.1, U5.14
unnamed: D10.1, U6.14
unnamed: D11.1, U7.14
unnamed: D12.1, R60.2, U8.9, U8.12
unnamed: D12.2, U8.8
unnamed: D13.1, R61.2, U9.9, U9.12
unnamed: D13.2, U9.8
unnamed: D14.1, R62.2, U10.9, U10.12
unnamed: D14.2, U10.8
unnamed: D15.1, R63.2, U11.9, U11.12
unnamed: D15.2, U11.8
unnamed: D16.1, U8.14
unnamed: D17.1, U9.14
unnamed: D18.1, U10.14
unnamed: D19.1, U11.14
unnamed: D20.1, R92.2, U12.9, U12.12
unnamed: D20.2, U12.8
unnamed: D21.1, R93.2, U13.9, U13.12
unnamed: D21.2, U13.8
unnamed: D22.1, R94.2, U14.9, U14.12
unnamed: D22.2, U14.8
unnamed: D23.1, R95.2, U15.9, U15.12
unnamed: D23.2, U15.8
unnamed: D24.1, U12.14
unnamed: D25.1, U13.14
unnamed: D26.1, U14.14
unnamed: D27.1, U15.14
unnamed: D28.1, R124.2, U16.9, U16.12
unnamed: D28.2, U16.8
unnamed: D29.1, R125.2, U17.9, U17.12
unnamed: D29.2, U17.8
unnamed: D30.1, R126.2, U18.9, U18.12
unnamed: D30.2, U18.8
unnamed: D31.1, R127.2, U19.9, U19.12
unnamed: D31.2, U19.8
unnamed: D32.1, U16.14
unnamed: D33.1, U17.14
unnamed: D34.1, U18.14
unnamed: D35.1, U19.14
unnamed: J3.3, R4.1, R8.2
unnamed: J4.3, R5.1, R9.2
unnamed: J5.3, R6.1, R10.2
unnamed: J6.3, R7.1, R11.2
unnamed: J7.3, R36.1, R40.2
unnamed: J8.3, R37.1, R41.2
unnamed: J9.3, R38.1, R42.2
unnamed: J10.3, R39.1, R43.2
unnamed: J11.3, R68.1, R72.2
unnamed: J12.3, R69.1, R73.2
unnamed: J13.3, R70.1, R74.2
unnamed: J14.3, R71.1, R75.2
unnamed: J15.3, R100.1, R104.2
unnamed: J16.3, R101.1, R105.2
unnamed: J17.3, R102.1, R106.2
unnamed: J18.3, R103.1, R107.2
unnamed: R2.1, R3.2, U3.6
unnamed: R8.1, U4.3
unnamed: R9.1, U5.3
unnamed: R10.1, U6.3
unnamed: R11.1, U7.3
unnamed: R12.1, RV1.3
unnamed: R12.2, R13.2, U4.1, U4.2
unnamed: R13.1, R14.1, R24.2, U4.6
unnamed: R15.1, RV2.3
unnamed: R15.2, R16.2, U5.1, U5.2
unnamed: R16.1, R17.1, R25.2, U5.6
unnamed: R18.1, RV3.3
unnamed: R18.2, R19.2, U6.1, U6.2
unnamed: R19.1, R20.1, R26.2, U6.6
unnamed: R21.1, RV4.3
unnamed: R21.2, R22.2, U7.1, U7.2
unnamed: R22.1, R23.1, R27.2, U7.6
unnamed: R24.1, U4.7, U4.10
unnamed: R25.1, U5.7, U5.10
unnamed: R26.1, U6.7, U6.10
unnamed: R27.1, U7.7, U7.10
unnamed: R40.1, U8.3
unnamed: R41.1, U9.3
unnamed: R42.1, U10.3
unnamed: R43.1, U11.3
unnamed: R44.1, RV5.3
unnamed: R44.2, R45.2, U8.1, U8.2
unnamed: R45.1, R46.1, R56.2, U8.6
unnamed: R47.1, RV6.3
unnamed: R47.2, R48.2, U9.1, U9.2
unnamed: R48.1, R49.1, R57.2, U9.6
unnamed: R50.1, RV7.3
unnamed: R50.2, R51.2, U10.1, U10.2
unnamed: R51.1, R52.1, R58.2, U10.6
unnamed: R53.1, RV8.3
unnamed: R53.2, R54.2, U11.1, U11.2
unnamed: R54.1, R55.1, R59.2, U11.6
unnamed: R56.1, U8.7, U8.10
unnamed: R57.1, U9.7, U9.10
unnamed: R58.1, U10.7, U10.10
unnamed: R59.1, U11.7, U11.10
unnamed: R72.1, U12.3
unnamed: R73.1, U13.3
unnamed: R74.1, U14.3
unnamed: R75.1, U15.3
unnamed: R76.1, RV9.3
unnamed: R76.2, R77.2, U12.1, U12.2
unnamed: R77.1, R78.1, R88.2, U12.6
unnamed: R79.1, RV10.3
unnamed: R79.2, R80.2, U13.1, U13.2
unnamed: R80.1, R81.1, R89.2, U13.6
unnamed: R82.1, RV11.3
unnamed: R82.2, R83.2, U14.1, U14.2
unnamed: R83.1, R84.1, R90.2, U14.6
unnamed: R85.1, RV12.3
unnamed: R85.2, R86.2, U15.1, U15.2
unnamed: R86.1, R87.1, R91.2, U15.6
unnamed: R88.1, U12.7, U12.10
unnamed: R89.1, U13.7, U13.10
unnamed: R90.1, U14.7, U14.10
unnamed: R91.1, U15.7, U15.10
unnamed: R104.1, U16.3
unnamed: R105.1, U17.3
unnamed: R106.1, U18.3
unnamed: R107.1, U19.3
unnamed: R108.1, RV13.3
unnamed: R108.2, R109.2, U16.1, U16.2
unnamed: R109.1, R110.1, R120.2, U16.6
unnamed: R111.1, RV14.3
unnamed: R111.2, R112.2, U17.1, U17.2
unnamed: R112.1, R113.1, R121.2, U17.6
unnamed: R114.1, RV15.3
unnamed: R114.2, R115.2, U18.1, U18.2
unnamed: R115.1, R116.1, R122.2, U18.6
unnamed: R117.1, RV16.3
unnamed: R117.2, R118.2, U19.1, U19.2
unnamed: R118.1, R119.1, R123.2, U19.6
unnamed: R120.1, U16.7, U16.10
unnamed: R121.1, U17.7, U17.10
unnamed: R122.1, U18.7, U18.10
unnamed: R123.1, U19.7, U19.10
unnamed: RV1.2, U4.5
unnamed: RV2.2, U5.5
unnamed: RV3.2, U6.5
unnamed: RV4.2, U7.5
unnamed: RV5.2, U8.5
unnamed: RV6.2, U9.5
unnamed: RV7.2, U10.5
unnamed: RV8.2, U11.5
unnamed: RV9.2, U12.5
unnamed: RV10.2, U13.5
unnamed: RV11.2, U14.5
unnamed: RV12.2, U15.5
unnamed: RV13.2, U16.5
unnamed: RV14.2, U17.5
unnamed: RV15.2, U18.5
unnamed: RV16.2, U19.5
Vref: C8.1, C9.1, C11.1, R2.2, R32.1, R33.1, R34.1, R35.1, R64.1, R65.1, R66.1, R67.1, R96.1, R97.1, R98.1, R99.1, R128.1, R129.1, R130.1, R131.1, U1.15, U2.15, U3.1, U3.2

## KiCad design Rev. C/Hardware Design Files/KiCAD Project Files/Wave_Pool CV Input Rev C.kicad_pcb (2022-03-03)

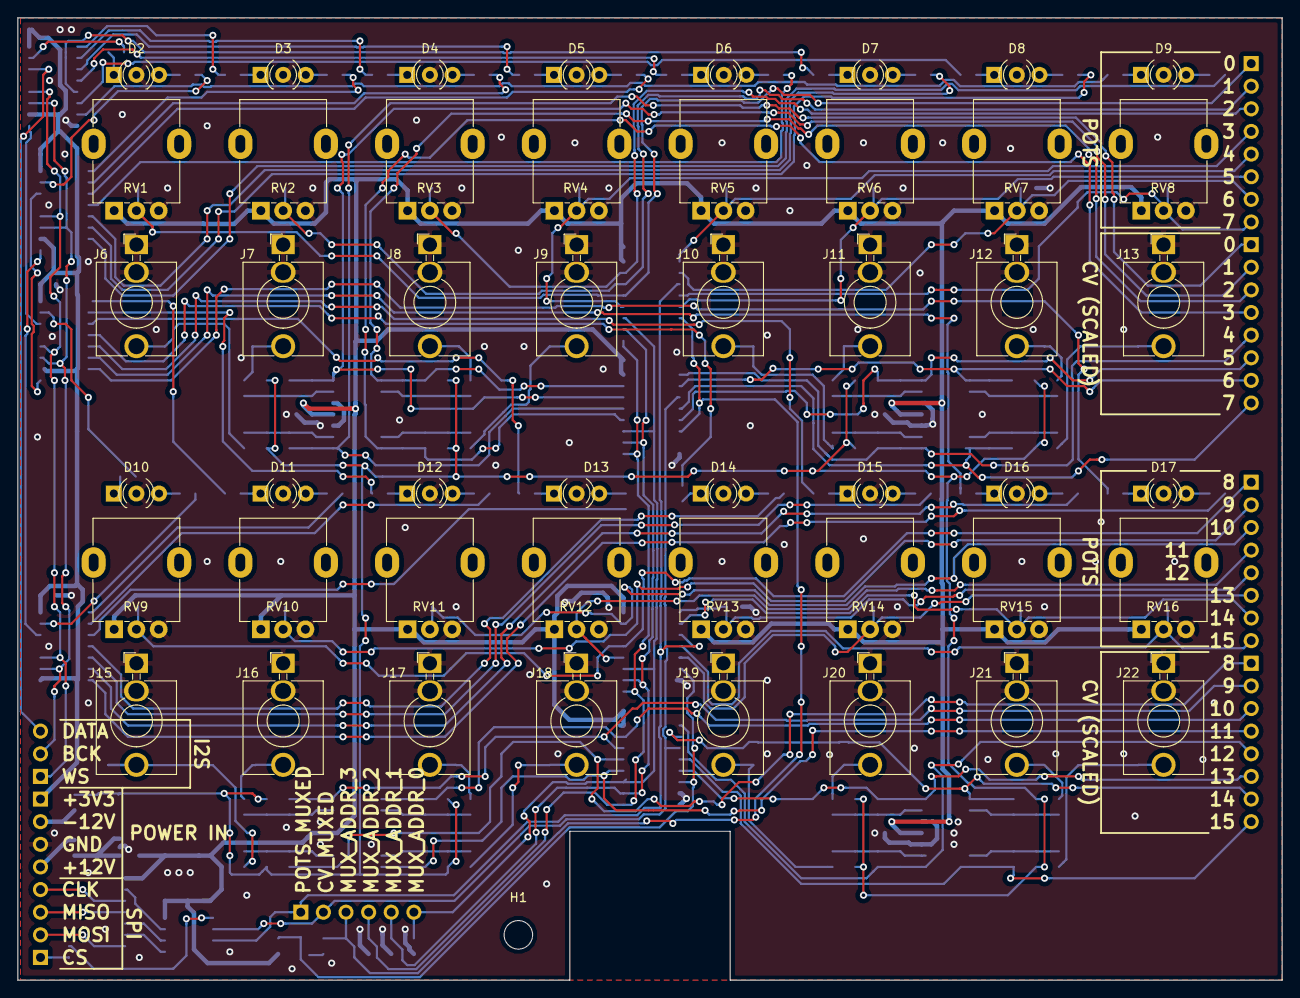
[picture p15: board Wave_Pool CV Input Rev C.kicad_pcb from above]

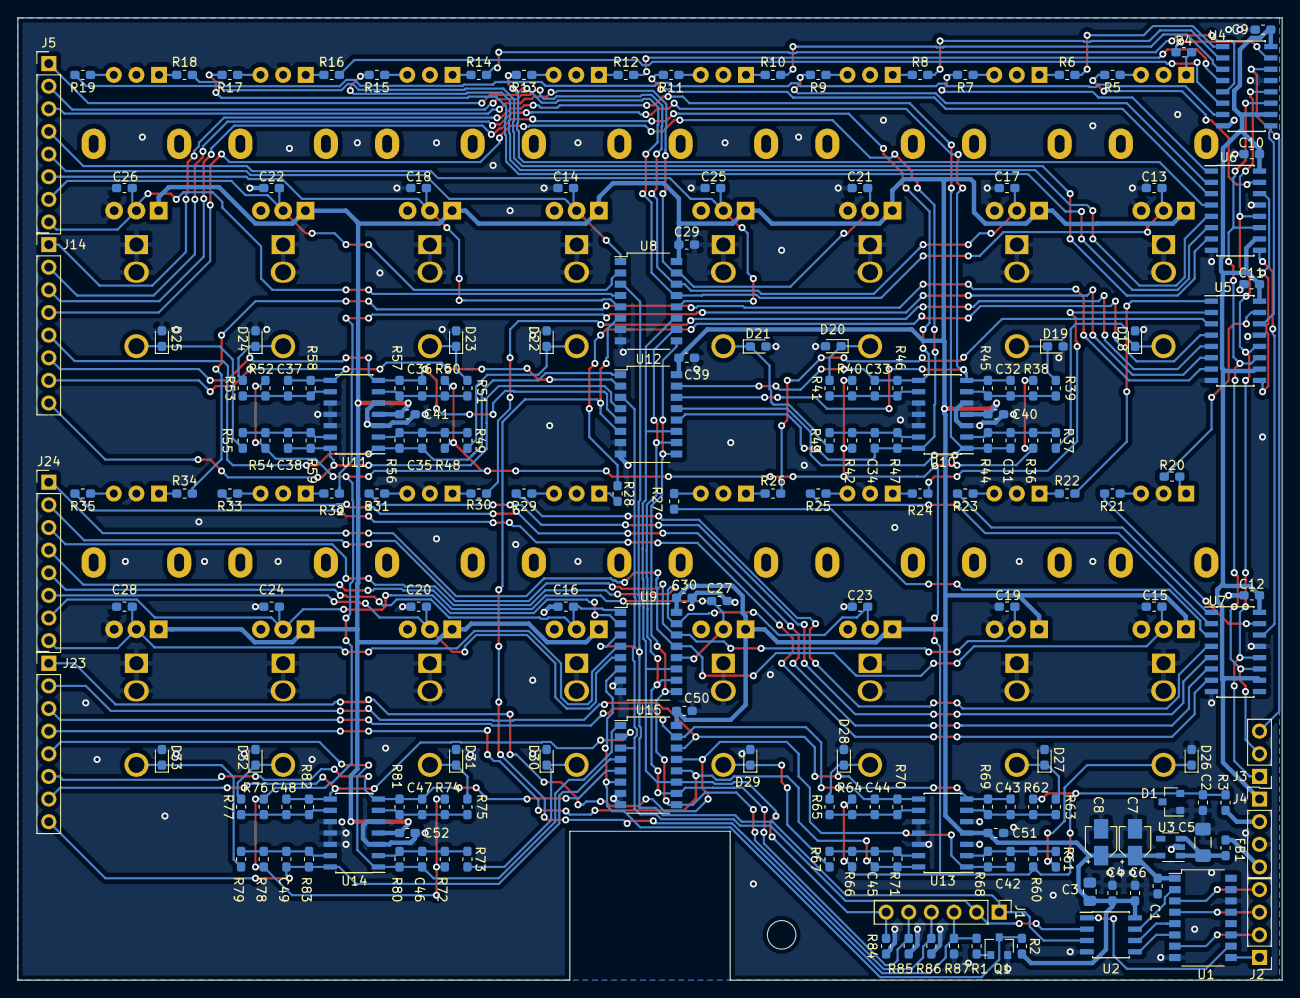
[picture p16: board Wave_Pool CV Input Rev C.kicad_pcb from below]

Board: 2 copper layers, 141.9 x 108.0 mm, 230 parts (181 on the bottom side), 157 nets.

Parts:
C1, C6, C9, C10, C11, C12, C13, C14, C15, C16, C17, C18, C19, C20, C21, C22, C23, C24, C25, C26, C27, C28, C29, C30, C39, C40, C41, C50, C51, C52: 100n; C_0603_1608Metric_Pad1.05x0.95mm_HandSolder
C2, C4: 1u; C_0603_1608Metric_Pad1.05x0.95mm_HandSolder
C3: 10u; C_0805_2012Metric_Pad1.15x1.40mm_HandSolder
C5: 22u; C_1206_3216Metric_Pad1.42x1.75mm_HandSolder
C7, C8: 10u; CP_Elec_3x5.4
C31, C32, C33, C34, C35, C36, C37, C38, C42, C43, C44, C45, C46, C47, C48, C49: 1n; C_0603_1608Metric_Pad1.05x0.95mm_HandSolder
D1: LM4040DBZ-10; SOT-23
D2, D3, D4, D5, D6, D7, D8, D9, D10, D11, D12, D13, D14, D15, D16, D17: Kingbright W115WSURKMGKW; LED_D3.0mm-3
D18, D19, D20, D21, D22, D23, D24, D25, D26, D27, D28, D29, D30, D31, D32, D33: D_TVS; D_0603_1608Metric_Pad1.05x0.95mm_HandSolder
FB1: Ferrite_Bead; L_0603_1608Metric_Pad1.05x0.95mm_HandSolder
H1: MountingHole; MountingHole_3.2mm_M3
J1: Conn_01x06; PinHeader_1x06_P2.54mm_Vertical
J2, J4: Conn_01x04; PinHeader_1x04_P2.54mm_Vertical
J3: Conn_01x03; PinHeader_1x03_P2.54mm_Vertical
J5, J14, J23, J24: Conn_01x08; PinHeader_1x08_P2.54mm_Vertical
J6, J7, J8, J9, J10, J11, J12, J13, J15, J16, J17, J18, J19, J20, J21, J22: Thonkiconn_Mono; Jack_3.5mm_Thonkiconn_Mono
Q1: MMBT3904; SOT-23
R1, R2, R84, R85, R86, R87: 10k; R_0603_1608Metric_Pad1.05x0.95mm_HandSolder
R3, R4, R6, R8, R10, R12, R14, R16, R18, R20, R22, R24, R26, R28, R30, R32, R34: 2.4k; R_0603_1608Metric_Pad1.05x0.95mm_HandSolder
R5, R7, R9, R11, R13, R15, R17, R19, R21, R23, R25, R27, R29, R31, R33, R35: 1.5k; R_0603_1608Metric_Pad1.05x0.95mm_HandSolder
R36, R38, R40, R42, R48, R50, R52, R54, R60, R62, R64, R66, R72, R74, R76, R78: 200k; R_0603_1608Metric_Pad1.05x0.95mm_HandSolder
R37, R39, R41, R43, R49, R51, R53, R55, R61, R63, R65, R67, R73, R75, R77, R79: 100k; R_0603_1608Metric_Pad1.05x0.95mm_HandSolder
R44, R45, R46, R47, R56, R57, R58, R59, R68, R69, R70, R71, R80, R81, R82, R83: 33k; R_0603_1608Metric_Pad1.05x0.95mm_HandSolder
RV1, RV2, RV3, RV4, RV5, RV6, RV7, RV8, RV9, RV10, RV11, RV12, RV13, RV14, RV15, RV16: R_POT_US; Potentiometer_Alpha_9mm_Single_Vertical
U1: 4050; SOP-16_4.4x10.4mm_P1.27mm
U2: MCP3202; SOIC-8_3.9x4.9mm_P1.27mm
U3: LD2981ABM33TR; SOT-23-5
U4, U5, U6, U7: 74HC595; SOIC-16_3.9x9.9mm_P1.27mm
U8, U9, U12, U15: 4051; SOP-16_4.4x10.4mm_P1.27mm
U10, U11, U13, U14: MCP6004; SOIC-14_3.9x8.7mm_P1.27mm

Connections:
+3.3VA: C1.1, C3.1, C4.1, C6.1, C7.1, C8.1, C29.1, C30.1, C39.1, C40.1, C41.1, C50.1, C51.1, C52.1, R2.2, RV1.1, RV2.1, RV3.1, RV4.1, RV5.1, RV6.1, RV7.1, RV8.1, RV9.1, RV10.1, RV11.1, RV12.1, RV13.1, RV14.1, RV15.1, RV16.1, U1.1, U2.8, U3.5, U8.16, U9.16, U10.4, U11.4, U12.16, U13.4, U14.4, U15.16
+3V3: C9.1, C10.1, C11.1, C12.1, J4.1, U4.10, U4.16, U5.10, U5.16, U6.10, U6.16, U7.10, U7.16
+12V: FB1.2, J4.4
-12V: J4.2, R3.1
/ATTENUVERTER_POTS/CV_ATT_0: C13.1, J5.1, RV1.2, U8.13
/ATTENUVERTER_POTS/CV_ATT_1: C17.1, J5.2, RV2.2, U8.14
/ATTENUVERTER_POTS/CV_ATT_2: C21.1, J5.3, RV3.2, U8.15
/ATTENUVERTER_POTS/CV_ATT_3: C25.1, J5.4, RV4.2, U8.12
/ATTENUVERTER_POTS/CV_ATT_4: C14.1, J5.5, RV5.2, U8.1
/ATTENUVERTER_POTS/CV_ATT_5: C18.1, J5.6, RV6.2, U8.5
/ATTENUVERTER_POTS/CV_ATT_6: C22.1, J5.7, RV7.2, U8.2
/ATTENUVERTER_POTS/CV_ATT_7: C26.1, J5.8, RV8.2, U8.4
/ATTENUVERTER_POTS/CV_ATT_8: C15.1, J24.1, RV9.2, U9.13
/ATTENUVERTER_POTS/CV_ATT_9: C19.1, J24.2, RV10.2, U9.14
/ATTENUVERTER_POTS/CV_ATT_10: C23.1, J24.3, RV11.2, U9.15
/ATTENUVERTER_POTS/CV_ATT_11: C27.1, J24.4, RV12.2, U9.12
/ATTENUVERTER_POTS/CV_ATT_12: C16.1, J24.5, RV13.2, U9.1
/ATTENUVERTER_POTS/CV_ATT_13: C20.1, J24.6, RV14.2, U9.5
/ATTENUVERTER_POTS/CV_ATT_14: C24.1, J24.7, RV15.2, U9.2
/ATTENUVERTER_POTS/CV_ATT_15: C28.1, J24.8, RV16.2, U9.4
/CV_ATT_MUXED: J1.1, U2.3, U8.3, U9.3
/CV_INPUTS/CV_INPUTS_BOTTOM_ROW/CV_IN_8: C42.1, J23.1, R68.1, U13.1, U15.13
/CV_INPUTS/CV_INPUTS_BOTTOM_ROW/CV_IN_9: C43.1, J23.2, R69.1, U13.7, U15.14
/CV_INPUTS/CV_INPUTS_BOTTOM_ROW/CV_IN_10: C44.1, J23.3, R70.1, U13.8, U15.15
/CV_INPUTS/CV_INPUTS_BOTTOM_ROW/CV_IN_11: C45.1, J23.4, R71.1, U13.14, U15.12
/CV_INPUTS/CV_INPUTS_BOTTOM_ROW/CV_IN_12: C46.1, J23.5, R80.1, U14.1, U15.1
/CV_INPUTS/CV_INPUTS_BOTTOM_ROW/CV_IN_13: C47.1, J23.6, R81.1, U14.7, U15.5
/CV_INPUTS/CV_INPUTS_BOTTOM_ROW/CV_IN_14: C48.1, J23.7, R82.1, U14.8, U15.2
/CV_INPUTS/CV_INPUTS_BOTTOM_ROW/CV_IN_15: C49.1, J23.8, R83.1, U14.14, U15.4
/CV_INPUTS/CV_INPUTS_TOP_ROW/CV_IN_0: C31.1, J14.1, R44.1, U10.1, U12.13
/CV_INPUTS/CV_INPUTS_TOP_ROW/CV_IN_1: C32.1, J14.2, R45.1, U10.7, U12.14
/CV_INPUTS/CV_INPUTS_TOP_ROW/CV_IN_2: C33.1, J14.3, R46.1, U10.8, U12.15
/CV_INPUTS/CV_INPUTS_TOP_ROW/CV_IN_3: C34.1, J14.4, R47.1, U10.14, U12.12
/CV_INPUTS/CV_INPUTS_TOP_ROW/CV_IN_4: C35.1, J14.5, R56.1, U11.1, U12.1
/CV_INPUTS/CV_INPUTS_TOP_ROW/CV_IN_5: C36.1, J14.6, R57.1, U11.7, U12.5
/CV_INPUTS/CV_INPUTS_TOP_ROW/CV_IN_6: C37.1, J14.7, R58.1, U11.8, U12.2
/CV_INPUTS/CV_INPUTS_TOP_ROW/CV_IN_7: C38.1, J14.8, R59.1, U11.14, U12.4
/CV_IN_MUXED: J1.2, U2.2, U12.3, U15.3
/I2S_BCK: J3.2, U4.11, U5.11, U6.11, U7.11
/I2S_DATA: J3.3, U4.14
/I2S_WS: J3.1, U4.12, U5.12, U6.12, U7.12
/LEDS/LED_G_0: R5.2, U6.15
/LEDS/LED_G_1: R7.2, U6.1
/LEDS/LED_G_2: R9.2, U6.2
/LEDS/LED_G_3: R11.2, U6.3
/LEDS/LED_G_4: R13.2, U6.4
/LEDS/LED_G_5: R15.2, U6.5
/LEDS/LED_G_6: R17.2, U6.6
/LEDS/LED_G_7: R19.2, U6.7
/LEDS/LED_G_8: R21.2, U7.15
/LEDS/LED_G_9: R23.2, U7.1
/LEDS/LED_G_10: R25.2, U7.2
/LEDS/LED_G_11: R27.2, U7.3
/LEDS/LED_G_12: R29.2, U7.4
/LEDS/LED_G_13: R31.2, U7.5
/LEDS/LED_G_14: R33.2, U7.6
/LEDS/LED_G_15: R35.2, U7.7
/LEDS/LED_R_0: R4.2, U4.15
/LEDS/LED_R_1: R6.2, U4.1
/LEDS/LED_R_2: R8.2, U4.2
/LEDS/LED_R_3: R10.2, U4.3
/LEDS/LED_R_4: R12.2, U4.4
/LEDS/LED_R_5: R14.2, U4.5
/LEDS/LED_R_6: R16.2, U4.6
/LEDS/LED_R_7: R18.2, U4.7
/LEDS/LED_R_8: R20.2, U5.15
/LEDS/LED_R_9: R22.2, U5.1
/LEDS/LED_R_10: R24.2, U5.2
/LEDS/LED_R_11: R26.2, U5.3
/LEDS/LED_R_12: R28.2, U5.4
/LEDS/LED_R_13: R30.2, U5.5
/LEDS/LED_R_14: R32.2, U5.6
/LEDS/LED_R_15: R34.2, U5.7
/MUX_ADDR_0: J1.6, R84.1, U8.11, U9.11, U12.11, U15.11
/MUX_ADDR_1: J1.5, R85.1, U8.10, U9.10, U12.10, U15.10
/MUX_ADDR_2: J1.4, R86.1, U8.9, U9.9, U12.9, U15.9
/MUX_ADDR_3: J1.3, R1.2, R87.1, U8.6, U12.6
/MUX_ADDR_3n: Q1.3, R2.1, U9.6, U15.6
/SPI_CLK: J2.4, U1.3
/SPI_CLK_BUF: U1.2, U2.7
/SPI_CS_ADC: J2.1, U1.9
/SPI_CS_ADC_BUF: U1.10, U2.1
/SPI_MISO: U1.5, U2.6
/SPI_MISO_BUF: J2.3, U1.4
/SPI_MOSI: J2.2, U1.7
/SPI_MOSI_BUF: U1.6, U2.5
AREF_-10: C2.1, D1.2, R3.2, R36.2, R38.2, R40.2, R42.2, R48.2, R50.2, R52.2, R54.2, R60.2, R62.2, R64.2, R66.2, R72.2, R74.2, R76.2, R78.2
GND: C1.2, C2.2, C3.2, C4.2, C5.2, C6.2, C7.2, C8.2, C9.2, C10.2, C11.2, C12.2, C13.2, C14.2, C15.2, C16.2, C17.2, C18.2, C19.2, C20.2, C21.2, C22.2, C23.2, C24.2, C25.2, C26.2, C27.2, C28.2, C29.2, C30.2, C39.2, C40.2, C41.2, C50.2, C51.2, C52.2, D1.1, D2.2, D3.2, D4.2, D5.2, D6.2, D7.2, D8.2, D9.2, D10.2, D11.2, D12.2, D13.2, D14.2, D15.2, D16.2, D17.2, D18.2, D19.2, D20.2, D21.2, D22.2, D23.2, D24.2, D25.2, D26.2, D27.2, D28.2, D29.2, D30.2, D31.2, D32.2, D33.2, J4.3, J6.1, J6.2, J7.1, J7.2, J8.1, J8.2, J9.1, J9.2, J10.1, J10.2, J11.1, J11.2, J12.1, J12.2, J13.1, J13.2, J15.1, J15.2, J16.1, J16.2, J17.1, J17.2, J18.1, J18.2, J19.1, J19.2, J20.1, J20.2, J21.1, J21.2, J22.1, J22.2, Q1.2, R84.2, R85.2, R86.2, R87.2, RV1.3, RV2.3, RV3.3, RV4.3, RV5.3, RV6.3, RV7.3, RV8.3, RV9.3, RV10.3, RV11.3, RV12.3, RV13.3, RV14.3, RV15.3, RV16.3, U1.8, U1.11, U1.14, U2.4, U3.2, U4.8, U4.13, U5.8, U5.13, U6.8, U6.13, U7.8, U7.13, U8.7, U8.8, U9.7, U9.8, U10.3, U10.5, U10.10, U10.11, U10.12, U11.3, U11.5, U11.10, U11.11, U11.12, U12.7, U12.8, U13.3, U13.5, U13.10, U13.11, U13.12, U14.3, U14.5, U14.10, U14.11, U14.12, U15.7, U15.8
unnamed: C5.1, FB1.1, U3.1, U3.3
unnamed: C31.2, R36.1, R37.1, R44.2, U10.2
unnamed: C32.2, R38.1, R39.1, R45.2, U10.6
unnamed: C33.2, R40.1, R41.1, R46.2, U10.9
unnamed: C34.2, R42.1, R43.1, R47.2, U10.13
unnamed: C35.2, R48.1, R49.1, R56.2, U11.2
unnamed: C36.2, R50.1, R51.1, R57.2, U11.6
unnamed: C37.2, R52.1, R53.1, R58.2, U11.9
unnamed: C38.2, R54.1, R55.1, R59.2, U11.13
unnamed: C42.2, R60.1, R61.1, R68.2, U13.2
unnamed: C43.2, R62.1, R63.1, R69.2, U13.6
unnamed: C44.2, R64.1, R65.1, R70.2, U13.9
unnamed: C45.2, R66.1, R67.1, R71.2, U13.13
unnamed: C46.2, R72.1, R73.1, R80.2, U14.2
unnamed: C47.2, R74.1, R75.1, R81.2, U14.6
unnamed: C48.2, R76.1, R77.1, R82.2, U14.9
unnamed: C49.2, R78.1, R79.1, R83.2, U14.13
unnamed: D2.1, R4.1
unnamed: D2.3, R5.1
unnamed: D3.1, R6.1
unnamed: D3.3, R7.1
unnamed: D4.1, R8.1
unnamed: D4.3, R9.1
unnamed: D5.1, R10.1
unnamed: D5.3, R11.1
unnamed: D6.1, R12.1
unnamed: D6.3, R13.1
unnamed: D7.1, R14.1
unnamed: D7.3, R15.1
unnamed: D8.1, R16.1
unnamed: D8.3, R17.1
unnamed: D9.1, R18.1
unnamed: D9.3, R19.1
unnamed: D10.1, R20.1
unnamed: D10.3, R21.1
unnamed: D11.1, R22.1
unnamed: D11.3, R23.1
unnamed: D12.1, R24.1
unnamed: D12.3, R25.1
unnamed: D13.1, R26.1
unnamed: D13.3, R27.1
unnamed: D14.1, R28.1
unnamed: D14.3, R29.1
unnamed: D15.1, R30.1
unnamed: D15.3, R31.1
unnamed: D16.1, R32.1
unnamed: D16.3, R33.1
unnamed: D17.1, R34.1
unnamed: D17.3, R35.1
unnamed: D18.1, J6.3, R37.2
unnamed: D19.1, J7.3, R39.2
unnamed: D20.1, J8.3, R41.2
unnamed: D21.1, J9.3, R43.2
unnamed: D22.1, J10.3, R49.2
unnamed: D23.1, J11.3, R51.2
unnamed: D24.1, J12.3, R53.2
unnamed: D25.1, J13.3, R55.2
unnamed: D26.1, J15.3, R61.2
unnamed: D27.1, J16.3, R63.2
unnamed: D28.1, J17.3, R65.2
unnamed: D29.1, J18.3, R67.2
unnamed: D30.1, J19.3, R73.2
unnamed: D31.1, J20.3, R75.2
unnamed: D32.1, J21.3, R77.2
unnamed: D33.1, J22.3, R79.2
unnamed: Q1.1, R1.1
unnamed: U4.9, U5.14
unnamed: U5.9, U6.14
unnamed: U6.9, U7.14

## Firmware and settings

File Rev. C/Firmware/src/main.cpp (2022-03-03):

#include <Arduino.h>
#include <Oscillator.h>
#include <MCP3008.h>
#include <MCP3208.h>
#include <MUXManager.h>

#define ARDUINOOSC_ENABLE_ETHER
#include <ArduinoOSC.h>
#include <OSCBundleClient.h>

#include <driver/ledc.h>
#include <driver/i2s.h>
#include <freertos/queue.h>

#define FRAMERATE 60
#define NUM_PARAMS 16
#define ETHER_SS_PIN 17
#define I2S_BCK_PIN 26
#define I2S_WS_PIN 25
#define I2S_DOUT_PIN 22

// #define CE0_PIN 32  //sets ADCs on HSPI
// #define CE1_PIN 33

#define CE0_PIN 17 //sets ADCs on VSPI
#define CE1_PIN 5
// you'll have to change this later since the ethernet thing runs
// on VSPI

const char *ssid = "ESP32 Access Point";
const char *password = "password";

const IPAddress ip(192, 168, 1, 201);
const IPAddress gateway(192, 168, 1, 1);
const IPAddress subnet(255, 255, 255, 0);

uint8_t mac[] = {
    0xDE, 0xAD, 0xBE, 0xEF, 0xFE, 0xED};

static const String params[] = {
    "lum", "mix", "hue", "sat", "x", "y", "z", "rot",
    "bri", "flt", "res", "con", "hmod", "hoff", "hlfo", "del"};

enum led_color
{
  green,
  red
};

MUXManager *muxManager;

SemaphoreHandle_t xSemaphoreMUX = NULL;
SemaphoreHandle_t xSemaphoreSPI = NULL;

QueueHandle_t queue;
void TaskDummyADC(void *pvParameters);
void TaskOscWiFi(void *pvParameters);
void TaskOscEther(void *pvParameters);
void TaskReadADC(void *pvParameters);
void TaskLEDs(void *pvParameters);
void TaskI2SIO(void *pvParameters);

inline TickType_t hzToTickPeriod(const uint8_t hz);
inline uint8_t getLEDindex(const uint8_t input_index, const led_color color);

void setup()
{
  // put your setup code here, to run once:
  Serial.begin(115200);

  muxManager = new MUXManager();

  xSemaphoreMUX = xSemaphoreCreateMutex();
  xSemaphoreSPI = xSemaphoreCreateMutex();
  queue = xQueueCreate(5, NUM_PARAMS * sizeof(uint16_t));

  // xTaskCreatePinnedToCore(
  //     TaskOscWiFi, // pvTaskCode
  //     "OSC_send",  // name for humans
  //     2048,        // usStackDepth
  //     NULL,        // pvParameters
  //     3,           // uxPriority
  //     NULL,        // pvCreatedTask
  //     1);          // xCoreID

  xTaskCreatePinnedToCore(
      TaskDummyADC,
      "Dummy_Data",
      1024,
      NULL,
      2,
      NULL,
      1);

  // xTaskCreatePinnedToCore(
  //     TaskReadADC,
  //     "ADC_Read",
  //     2048,
  //     NULL,
  //     4,
  //     NULL,
  //     1);

  // xTaskCreatePinnedToCore(
  //     TaskOscEther, // pvTaskCode
  //     "OSC_send",   // name for humans
  //     2048,         // usStackDepth
  //     NULL,         // pvParameters
  //     3,            // uxPriority
  //     NULL,         // pvCreatedTask
  //     1);           // xCoreID

  // xTaskCreatePinnedToCore(
  //     TaskLEDs,
  //     "LED output",
  //     2048,
  //     NULL,
  //     2,
  //     NULL,
  //     1);

  xTaskCreatePinnedToCore(
      TaskI2SIO,
      "I2S I/O",
      4096,
      NULL,
      2,
      NULL,
      1);
}

void TaskDummyADC(void *pvParameters)
{
  (void)pvParameters;
  static TickType_t xLastWakeTime;
  static const TickType_t xFrequency = hzToTickPeriod(60);
  xLastWakeTime = xTaskGetTickCount();

  constexpr float frequency = 0.2;
  constexpr uint16_t amplitude = 2047;
  constexpr uint16_t offset = 0;
  static Oscillator osc(frequency, amplitude, offset);

  static int16_t vals[NUM_PARAMS] = {0};
  static uint8_t current = 0;

  for (;;)
  {
    vTaskDelayUntil(&xLastWakeTime, xFrequency);
    for (uint8_t i = 0; i < NUM_PARAMS; i++)
    {
      if (i % 2 == 0)
      {
        vals[i] = osc.getValue();
      }
      else
      {
        vals[i] = -1 * osc.getValue();
      }
      //Serial.printf("%d\t", vals[i]);
    }
    //Serial.print("\n");
    osc.update();

    // vTaskDelay(500 / portTICK_PERIOD_MS);

    // for (int i = 0; i < NUM_PARAMS; i++)
    // {
    //   vals[i] = 0;
    // }
    // vals[current % NUM_PARAMS] = (current < NUM_PARAMS ? 2048 : -2048);
    // current = (current + 1) % (NUM_PARAMS * 2);

    xQueueSendToBack(queue, &vals, 0);
  }
}

void TaskOscWiFi(void *pvParameters)
{
  (void)pvParameters;
  static TickType_t xLastWakeTime;
  static const TickType_t xFrequency = hzToTickPeriod(FRAMERATE);
  xLastWakeTime = xTaskGetTickCount();
  UBaseType_t stackHighwater = 2048;
  UBaseType_t prev = stackHighwater;

  // WiFi Stuff
  WiFi.disconnect(true, true); // disable wifi, erase ap info
  delay(2000);
  WiFi.mode(WIFI_AP);
  WiFi.softAP(ssid, password);
  delay(1000);
  WiFi.softAPsetHostname(ssid);
  WiFi.softAPConfig(ip, gateway, subnet);

  Serial.println("WiFi connected");
  Serial.println("IP Address: ");
  Serial.println(WiFi.softAPIP());

  //OSC
  static const String host = "192.168.1.202";
  static const uint16_t send_port = 7000;
  static const String addr = "/wp_cv/";
  static uint16_t vals[NUM_PARAMS];

  OscBundler<WiFiUDP> bundler;
  OscMessage msg;

  for (;;)
  {
    vTaskDelayUntil(&xLastWakeTime, xFrequency);
    if (xQueueReceive(queue, &vals, 10) == pdTRUE)
    {
      bundler.begin_bundle();
      for (int i = 0; i < NUM_PARAMS; i++)
      {
        msg.init(addr + params[i]).push(vals[i]);
        bundler.encode(msg);
      }
      bundler.end_bundle();
      bundler.send(host, send_port);
    }

    //stack monitoring
    stackHighwater = min(stackHighwater, uxTaskGetStackHighWaterMark(NULL));
    if (stackHighwater != prev)
    {
      Serial.println(stackHighwater);
      prev = stackHighwater;
    }
  }
}

void TaskOscEther(void *pvParameters)
{
  (void)pvParameters;
  static TickType_t xLastWakeTime;
  static const TickType_t xFrequency = hzToTickPeriod(FRAMERATE);
  xLastWakeTime = xTaskGetTickCount();
  UBaseType_t stackHighwater = 2048;
  UBaseType_t prev = stackHighwater;

  // Ethernet Stuff
  Ethernet.init(ETHER_SS_PIN);
  Ethernet.begin(mac, ip);

  if (Ethernet.hardwareStatus() == EthernetNoHardware)
  {
    Serial.println("Ethernet shield was not found.  Sorry, can't run without hardware. :(");
  }
  if (Ethernet.linkStatus() == LinkOFF)
  {
    Serial.println("Ethernet cable is not connected.");
  }

  //OSC
  static const String host = "192.168.1.202";
  static const uint16_t send_port = 7000;
  static const String addr = "/wp_cv/";
  static uint16_t vals[NUM_PARAMS];

  OscBundler<EthernetUDP> bundler;
  OscMessage msg;

  for (;;)
  {
    vTaskDelayUntil(&xLastWakeTime, xFrequency);
    if (xQueueReceive(queue, &vals, 10) == pdTRUE)
    {
      bundler.begin_bundle();
      for (int i = 0; i < NUM_PARAMS; i++)
      {
        msg.init(addr + params[i]).push(vals[i]);
        bundler.encode(msg);
      }
      bundler.end_bundle();
      bundler.send(host, send_port);
    }

    //stack monitoring
    stackHighwater = min(stackHighwater, uxTaskGetStackHighWaterMark(NULL));
    if (stackHighwater != prev)
    {
      Serial.println(stackHighwater);
      prev = stackHighwater;
    }
  }
}

void TaskReadADC(void *pvParameters)
{
  (void)pvParameters;
  static TickType_t xLastWakeTime;
  static const TickType_t xFrequency = hzToTickPeriod(FRAMERATE);
  xLastWakeTime = xTaskGetTickCount();
  UBaseType_t stackHighwater = 2048;
  UBaseType_t prev = stackHighwater;

  static MCP3208 adc1(CE0_PIN); // CV 1-8
  static uint16_t vals[NUM_PARAMS] = {0};
  static uint16_t vals_scaled[NUM_PARAMS] = {0};

  for (;;)
  {
    vTaskDelayUntil(&xLastWakeTime, xFrequency);
    if ((xSemaphoreMUX != NULL) && (xSemaphoreSPI != NULL))
    {
      if (xSemaphoreTake(xSemaphoreMUX, (TickType_t)xFrequency / 3) == pdTRUE)
      {
        if (xSemaphoreTake(xSemaphoreSPI, (TickType_t)xFrequency / 3) == pdTRUE)
        {
          muxManager->enable();

          muxManager->selectMUX(CV_IN_TOP_ROW);
          for (uint8_t i = 0; i < (NUM_PARAMS / 2); i++)
          {
            muxManager->selectChannel(i);
            vals[i] = adc1.readADC(0) - 2048;
          }

          muxManager->selectMUX(CV_IN_BOTTOM_ROW);
          for (uint8_t i = 0; i < (NUM_PARAMS / 2); i++)
          {
            muxManager->selectChannel(i);
            vals[8 + i] = adc1.readADC(0) - 2048;
          }

          muxManager->selectMUX(CV_ATT_TOP_ROW);
          for (uint8_t i = 0; i < (NUM_PARAMS / 2); i++)
          {
            muxManager->selectChannel(i);
            vals_scaled[i] = vals[i] * (float_t)((adc1.readADC(0) - 2048) / 2048);
          }

          muxManager->selectMUX(CV_ATT_BOTTOM_ROW);
          for (uint8_t i = 0; i < (NUM_PARAMS / 2); i++)
          {
            muxManager->selectChannel(i);
            vals_scaled[8 + i] = vals[i] * (float_t)((adc1.readADC(0) - 2048) / 2048);
          }

          xSemaphoreGive(xSemaphoreSPI);
        }
        xSemaphoreGive(xSemaphoreMUX);
      }

      for (uint8_t i = 0; i < NUM_PARAMS; i++)
      {
        Serial.printf("%d\t", vals_scaled[i]);
      }
      Serial.print("\n");

      xQueueSendToBack(queue, &vals, (TickType_t)xFrequency / 3);

      stackHighwater = min(stackHighwater, uxTaskGetStackHighWaterMark(NULL));
      if (stackHighwater != prev)
      {
        Serial.println(stackHighwater);
        prev = stackHighwater;
      }
    }
  }
}

void TaskLEDs(void *pvParameters)
{
  Serial.println("In LED task");
  (void)pvParameters;

  const mux_select_t led_muxes[] = {
      LED_R_TOP_ROW,
      LED_G_TOP_ROW,
      LED_R_BOTTOM_ROW,
      LED_G_BOTTOM_ROW,
  };

  static uint16_t vals[NUM_PARAMS] = {0};
  uint8_t ch;
  uint8_t offset;
  uint32_t led_duty = 0;
  TickType_t delay_amt = (1000 / (16 * 60)) / portTICK_PERIOD_MS;

  // PWM Timer configuration settings
  ledc_timer_config_t ledc_timer;
  // Set timer to High Speed Mode (allows seamless duty cycle changes)
  ledc_timer.speed_mode = LEDC_HIGH_SPEED_MODE;
  // Set the resolution of the duty cycle
  // This parameter is interdependent with frequency
  // higher frequency -> less duty resolution available
  ledc_timer.duty_resolution = LEDC_TIMER_11_BIT;
  // Select Timer 0 arbitrarily
  ledc_timer.timer_num = LEDC_TIMER_0;
  // Select frequency of 50 kHz arbitrarily
  ledc_timer.freq_hz = 5000;

  // Apply configuration settings
  ledc_timer_config(&ledc_timer);

  // PWM channel configuration settings
  ledc_channel_config_t ledc_channel = {
      .gpio_num = 12,
      .speed_mode = LEDC_HIGH_SPEED_MODE,
      .channel = LEDC_CHANNEL_0,
      .intr_type = LEDC_INTR_DISABLE,
      .timer_sel = LEDC_TIMER_0,
      .duty = 0};

  ledc_channel_config(&ledc_channel);

  // Initialize both the LEDs to 0 (off)
  ledc_set_duty(ledc_channel.speed_mode, ledc_channel.channel, 0);
  ledc_update_duty(ledc_channel.speed_mode, ledc_channel.channel);

  for (;;)
  {
    // Copy in the latest values, if available
    if (xQueueReceive(queue, &vals, 0) == pdTRUE)
    {
      Serial.println("got new values");
    }

    if (xSemaphoreMUX != NULL)
    {
      if (xSemaphoreTake(xSemaphoreMUX, 10) == pdTRUE)
      {
        for (int m = 0; m < 2; m++)
        {
          // For the bottom rows, we need to loop through the second half of the array
          //offset = 8 * (m % 2);
          muxManager->disable();
          muxManager->selectMUX(led_muxes[m]);
          for (ch = 0; ch < NUM_PARAMS / 2; ch++)
          {
            muxManager->disable();
            muxManager->selectChannel(ch);
            if (muxManager->getSelectedMUX() == LED_R_TOP_ROW) // Red LEDs
            {
              led_duty = 2048 - min((int)vals[ch], 2048);
            }
            else if (muxManager->getSelectedMUX() == LED_G_TOP_ROW) // Green LEDs
            {
              led_duty = max((int)vals[ch], 2048) - 2048;
            }
            ledc_set_duty(ledc_channel.speed_mode, ledc_channel.channel, led_duty);
            ledc_update_duty(ledc_channel.speed_mode, ledc_channel.channel);
            muxManager->enable();

            vTaskDelay(delay_amt);
            muxManager->disable();
          }
        }

        xSemaphoreGive(xSemaphoreMUX);
      }
    }
  }
}

void TaskI2SIO(void *pvParameters)
{
  (void)pvParameters;

  //configure i2s
  static const i2s_port_t i2s_num = I2S_NUM_0; //i2s port num

  // i2s peripheral is feeding shift registers.
  // each of the 32 bits will be its own pwm signal
  // the dma buffer will hold one cycle of the pwm signal
  // the length of the buffer is equal to the pwm resolution
  // 8 bit pwm means 256 samples
  // 4 buffers * 64 samples = 256 total samples

  static const i2s_config_t i2s_config = {
      .mode = (i2s_mode_t)(I2S_MODE_MASTER | I2S_MODE_TX),
      .sample_rate = 10000, //we want 32 signals at 5 kHz
      .bits_per_sample = I2S_BITS_PER_SAMPLE_16BIT,
      .channel_format = I2S_CHANNEL_FMT_RIGHT_LEFT,
      .communication_format = I2S_COMM_FORMAT_I2S_MSB,
      .intr_alloc_flags = 0,
      .dma_buf_count = 4,
      .dma_buf_len = 64,
      .use_apll = false};

  static const i2s_pin_config_t pin_config = {
      .bck_io_num = I2S_BCK_PIN,
      .ws_io_num = I2S_WS_PIN,
      .data_out_num = I2S_DOUT_PIN,
      .data_in_num = I2S_PIN_NO_CHANGE};

  if (i2s_driver_install(i2s_num, &i2s_config, 0, NULL) == ESP_OK)
  {
    Serial.println("i2s driver successfully installed.");
  }
  else
  {
    Serial.println("something didn't work installing the i2s driver");
  }

  if (i2s_set_pin(i2s_num, &pin_config) == ESP_OK)
  {
    Serial.println("i2s pins set.");
  }
  else
  {
    Serial.println("something went wrong setting i2s pins.");
  }

  i2s_set_clk(i2s_num, 5000 * 32, I2S_BITS_PER_SAMPLE_32BIT, I2S_CHANNEL_MONO);

  // uint32_t samples_data[5] = {
  //     0b01010101010101010101010101010101,
  //     0b00110011001100110011001100110011,
  //     0b00001111000011110000111100001111,
  //     0b00000000111111110000000011111111,
  //     0b00000000000000001111111111111111};

  size_t bytes_written;

  static size_t dma_buffer_size = i2s_config.dma_buf_count * i2s_config.dma_buf_len;
  // static size_t num_samples = sizeof(samples_data) / sizeof(uint32_t);

  // for (uint8_t i = 0; i < (dma_buffer_size / num_samples); i++)
  // {
  // i2s_write(i2s_num, &samples_data, sizeof(samples_data), &bytes_written, portMAX_DELAY);
  // }

  static int16_t test_vals[16];

  // for (uint8_t i = 0; i < 16; i++)
  // {
  //   if (i % 2 == 0)
  //   {
  //     test_vals[i] = 1024;
  //   }
  //   else
  //   {
  //     test_vals[i] = -1024;
  //   }
  // }

  // bit format
  // [0-7]      [8-15]      [16-23]   [24-31]
  // [Bottom R] [Bottom G]  [Top R]   [Top G]

  Serial.println("generated test values.");

  uint32_t samples_data[256] = {0};

  for (;;)
  {
    // receive latest scaled CV values
    if (xQueueReceive(queue, &test_vals, 100) == pdTRUE)
    {
      // uint8_t active_index = 0;
      // Serial.print("received: ");
      // for (uint8_t i = 0; i < NUM_PARAMS; i++)
      // {
      //   Serial.printf("%d\t", test_vals[i]);
      //   if (test_vals[i] != 0)
      //   {
      //     active_index = i;
      //   }
      // }
      // Serial.print("\n");
      // Serial.printf("Input Index: %d\tGreen LED index: %d\tRed LED index: %d\n", active_index, getLEDindex(active_index, green), getLEDindex(active_index, red));

      // expecting input between -2047 and 2047 (probably change this to floats later on)
      // generate the sample data
      for (uint8_t i = 0; i < 16; i++)
      {
        bool neg = test_vals[i] < 0;

        int16_t scaled = test_vals[i];
        if (neg)
        {
          scaled *= -1;
        }
        scaled = scaled >> 3;

        uint8_t green_index = getLEDindex(i, green);
        uint8_t red_index = getLEDindex(i, red);

        for (uint16_t j = 0; j < 256; j++)
        {
          // if positive, set green led on and red off
          if (neg != true)
          {
            // set pulse width of green
            if (scaled > j)
            {
              samples_data[j] |= (1UL << green_index);
            }
            else
            {
              samples_data[j] &= ~(1UL << green_index);
            }

            samples_data[j] &= ~(1UL << red_index);
          }
          // if negative, set green led off and red on
          else // (neg == true)
          {
            if (scaled > j)
            {
              samples_data[j] |= (1UL << red_index);
            }
            else
            {
              samples_data[j] &= ~(1UL << red_index);
            }
            samples_data[j] &= ~(1UL << green_index);
          }
          // else // if zero turn them both off
          // {
          //   samples_data[j] &= ~(1UL << green_index);
          //   samples_data[j] &= ~(1UL << red_index);
          // }
        }
      }

      // generate sample data
      // for (uint16_t i = 0; i < 256; i++)
      // {
      //   for (uint8_t j = 0; j < 16; j++)
      //   {
      //     //Serial.printf("1) test_vals[%d] = %d \n", j, test_vals[j]);
      //     if (test_vals[j] > 0)
      //     {
      //       // turn on Green
      //       // Set pulse width according to value
      //       if ((test_vals[j] >> 3) > i)
      //       {
      //         //Serial.printf("2) value to be shifted in: %ul \n", (1UL << (31 - j)));
      //         samples_data[i] |= (1UL << (getLEDindex(j, green)));
      //         //Serial.printf("3) samples_data[i] = %ul \n", samples_data[i]);
      //       }
      //       else
      //       {
      //         samples_data[i] &= ~(1UL << (getLEDindex(j, green)));
      //         //Serial.printf("4) samples_data[i] = %ul \n", samples_data[i]);
      //       }
      //       //Serial.printf("4.5) !(1UL << (15 - %d)) =  %ul \n", j, ~(1UL << (15 - j)));

      //       // turn off Red
      //       samples_data[i] &= ~(1UL << (getLEDindex(j, red)));
      //       //Serial.printf("5) samples_data[i] = %ul \n", samples_data[i]);
      //     }
      //     else if (test_vals[j] < 0)
      //     {
      //       // turn on red
      //       // Set pulse width according to value
      //       if (((-1 * test_vals[j]) >> 3) > i)
      //       {
      //         samples_data[i] |= (1UL << (getLEDindex(j, red)));
      //         //Serial.printf("6) samples_data[i] = %ul \n", samples_data[i]);
      //       }
      //       else
      //       {
      //         samples_data[i] &= ~(1UL << (getLEDindex(j, red)));
      //         //Serial.printf("7) samples_data[i] = %ul \n", samples_data[i]);
      //       }

      //       // turn off Green
      //       samples_data[i] &= ~(1UL << (getLEDindex(j, green)));
      //       //Serial.printf("8) samples_data[i] = %ul \n", samples_data[i]);
      //     }
      //     //Serial.printf("9) samples_data[i] = %ul \n", samples_data[i]);
      //   }
      //   //Serial.println();
      // }

      // write it to the i2s periphereal

      // for (uint16_t i = 0; i < 256; i++)
      // {
      //   Serial.printf("%d: ",samples_data[i]);
      // }

      // note: something really didn't work here
      // // debug : print the samples data in a readable format:
      // Serial.println("generated: ");
      // for(uint8_t i = 0; i < 32; i++)
      // {
      //   for(uint16_t j = 0; j < 256; j++)
      //   {
      //     uint8_t c;
      //     uint8_t val = samples_data[j] & (1UL << (31 - i));
      //     if (val == 0)
      //     {
      //       c = 0;
      //     } else
      //     {
      //       c = 1;
      //     }

      //     Serial.printf("%d", c);
      //   }
      //   Serial.printf("\n");
      // }
      // Serial.printf("\n");

      i2s_write(i2s_num, &samples_data, 256 * 4, &bytes_written, portMAX_DELAY);
      //Serial.printf("%d bytes written to the i2s dma buffer.\n", bytes_written);

    }

    // for (uint8_t i = 0; i < dma_buffer_size; i++)
    // {
    //   i2s_write(i2s_num, &(samples_data[0]), sizeof(uint32_t), &bytes_written, portMAX_DELAY);
    // }

    // vTaskDelay(500 / portTICK_PERIOD_MS);

    // for (uint8_t i = 0; i < dma_buffer_size; i++)
    // {
    //   i2s_write(i2s_num, &(samples_data[4]), sizeof(uint32_t), &bytes_written, portMAX_DELAY);
    // }

    // vTaskDelay(500 / portTICK_PERIOD_MS);
  }
}

inline TickType_t hzToTickPeriod(const uint8_t hz)
{
  return (((float)1 / hz) * 1000) / portTICK_PERIOD_MS;
}

void loop()
{
  // put your main code here, to run repeatedly:

  // Not using loop(), program is tasked based
  vTaskDelete(NULL);
}

// I2S is shifting in MSB first
// 32 bit shift register format
// bit format
// [0:7]      [8:15]      [16:23]     [24:31]
// [TG 0:7]   [TR 0:7]    [BG 8:15]   [BR 8:15]

// input index
// [0-7]  Top row (left to right)
// [8-15] Bottom Row
inline uint8_t getLEDindex(const uint8_t input_index, const led_color color)
{
  uint8_t result;
  if (color == green)
  {
    result = input_index % 8 + (input_index >= 8 ? 16 : 0);
  }
  else // (color == red)
  {
    result = input_index % 8 + (input_index >= 8 ? 24 : 8);
  }
  return result;
}

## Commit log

2020-09-11 Added 2nd mcp and OSC, sampling less buggy now.
    [main.cpp]
2022-03-03 Added HW design files
    Added HW design files for Rev. B:
    -KiCAD project files
    -PCB gerber files for manufacturing
    -Front Panel gerber files for manufacturing
    -Schematic PDF
    -BOM with Mouser project link
    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
    [CV_INPUTS_BOTTOM_ROW.sch, CV_Input_1-4.sch, CV_Input_13-16.sch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]
2022-03-03 Added analog MUX logic and LED control
    updated analog read task to implement MUX switching logic
    Added LED control logic using I2S and shift registers
